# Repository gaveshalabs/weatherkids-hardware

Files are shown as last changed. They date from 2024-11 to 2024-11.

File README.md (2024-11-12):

# WeatherKids Weather Computer

WeatherKids is an engaging climate education program where children learn about climate change hands-on using a small, open-source weather station called the **Weather Computer**. This repository contains source code for both versions, **v1.0** and **v2.0**, of the Weather Computer. It is licensed under the **CERN Open Hardware License - W**, making it free to use, modify, and share in compliance with the license terms.

## Overview

The WeatherKids Weather Computer is designed to help young learners understand key aspects of weather and climate. Through real-time data collection and analysis, children learn about:

- Temperature
- Humidity
- Atmospheric Pressure
- And optional TVOC sensor

These metrics contribute to building awareness around climate science and inspire further exploration in STEM.

## Versions

### Version 1.0
- **Released**: 2022 December
- **Features**: 
    - Basic weather measurements (temperature, humidity,  pressure and optional TVOC sensor)
 
KNOWN issues - Charging mechanism doesn't work properly in fog conditions

### Version 2.0
- **Released**: 2023 December
- **Features**: 
    - Compact design with Li-Polimer battery
    - Sperate Action card to mearsure solar power and provide power to main board.

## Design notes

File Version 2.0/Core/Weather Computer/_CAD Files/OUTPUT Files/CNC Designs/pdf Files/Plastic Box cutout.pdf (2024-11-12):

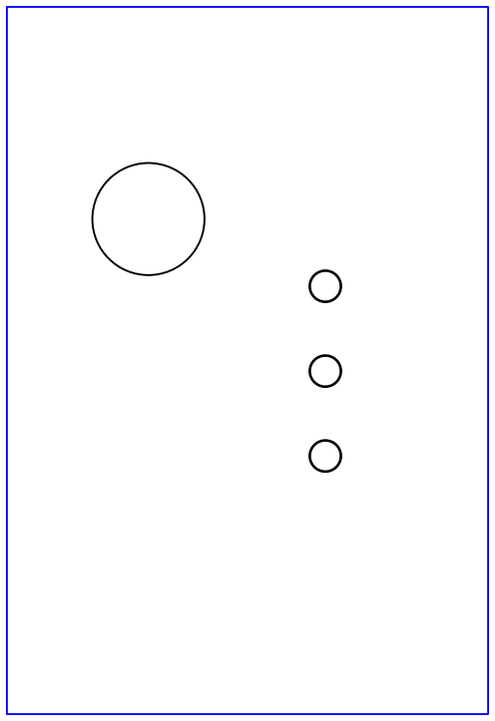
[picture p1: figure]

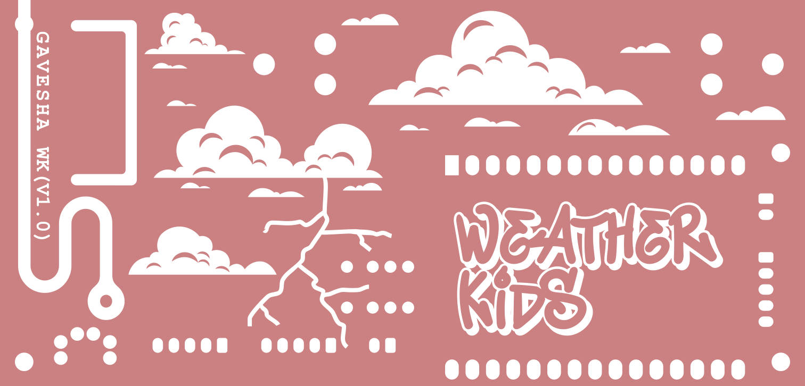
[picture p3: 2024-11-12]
Version 2.0/Core/Weather Computer/PROJECT_LIB/Bottom SilkScreen.png

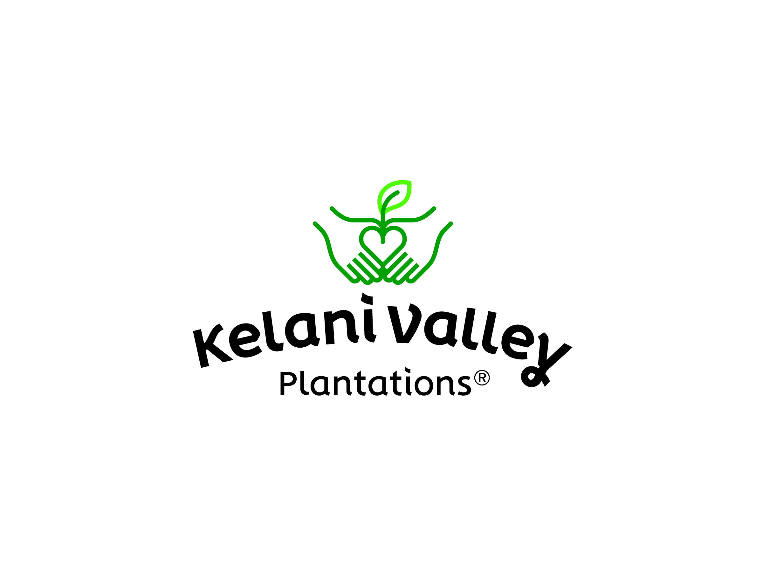
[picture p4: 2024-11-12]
Version 2.0/Core/Weather Computer/_CAD Files/Stickers/Resource Files/KVPL_CMYK.jpg

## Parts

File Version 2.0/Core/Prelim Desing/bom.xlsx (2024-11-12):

Designator | Footprint | Value | JLCPCB Part #
C1, C10, C13 | 402 | 1uF | C52923
C11 | 603 | 22uF | C59461
C12 | 402 | 0.1uF | C141382
C14, C15, C17, C24, C7, C9 | 805 | 10uF | C15850
C16, C18, C19, C2, C20, C21, C4 | 402 | 100nF | C1525
C23 | CP_EIA-3528-12_Kemet-T | 100uF | C16133
C25 | 402 | 4.7uF | C23733
C5 | 402 | 10uF | C15525
C6 | 603 | 47nF | C1622
C8 | 402 | 1nF | C1523
D1, D2, D5 | 805 | LED | C34499
D3 | D_SOD-323 | SS54 | C2128
D4 | D_SMA | SS54 | C22452
J1 | JST_PH_S2B-PH-SM4-TB_1x02-1MP_P2.00mm_Horizontal | Conn_01x02 | C295747
L1, L2 | WPN252010U | 1uH | C279952
R1 | 402 | 3.3k | C310224
R10, R2, R7 | 402 | 330R | C25104
R3,R11, R12, R13, R15, R17, R18, R19, R20, R21, R22, R23, R4, R8, R9 | 402 | 10k | C25744
R14 | 603 | 450k | C1395420
R16 | 402 | 200k | C25764
R24 | 402 | 3.6k | C310258
R5 | 402 | 510k | C11616
R6 | 402 | 68k | C36871
RV1 | 402 | AVRM1005C6R8NT331N | C574031
SW1, SW2, SW3, SW4 | SKRTLB | SW_Push | C127481
U1 | Texas_S-PWQFN-N24_EP2.7x2.7mm_ThermalVias | BQ25601 | C468236
U10, U11, U12, U13, U14 | SOT-23-5 | SN74LV1T34DVBR | C100024
U3 | DRL0006A | TPS61023DRL | C919459
U4 | SOT-223 | TLV1117LV30DCYR | C507264
U5 | AGS10 | AGS10 | C3012632
U6 | AHT20 | AHT20 | C3012622
U7 | SOIC-8_3.9x4.9mm_P1.27mm | PCF8563T | C7440
U8 | Bosch_LGA-8_2x2.5mm_P0.65mm_ClockwisePinNumbering | BMP280 | C83291
U9 | PCA9306DCUR | PCA9306DCUR | C33196
Y1 | Crystal_SMD_3215-2Pin_3.2x1.5mm | 32.768kHz | C32346

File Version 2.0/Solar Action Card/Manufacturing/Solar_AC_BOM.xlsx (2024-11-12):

C14663 | Footprint | Quantity | Value | LCSC Part #
C1, C16, C2, C10, C11, C13, C6 | 603 | 7 | 100nF | C14663
C12 | 603 | 1 | 10uF | C96446
C14 | 603 | 1 | 3.3nF | C1613
C15 | 603 | 1 | 22uF | C59461
C3 | 402 | 1 | 4.7uF | C23733
C4 | 402 | 1 | 10nF | C15195
C5 | 402 | 1 | 1uF | C52923
C8 | CP_EIA-3528-12_Kemet-T | 1 | 100uF | C16133
C9 | 805 | 1 | 10uF | C15850
J4 | USB_C_Receptacle_HRO_TYPE-C-31-M-12 | 1 | USB_C_Receptacle_USB2.0 | C165948
L1 | L_Sunlord_MWSA0518_5.4x5.2mm | 1 | 2.2uH | C408345
Q1, Q2 | SOT-23 | 2 | 2N7002E | C8545
R1, R15, R16, R2, R3, R5, R7, R8, R12 | 402 | 9 | 10k | C25744
R10 | 603 | 1 | 750k | C441908
R11 | 603 | 1 | 270k | C2889163
R13 | 1206 | 1 | 50m | C912768
R14 | R_Axial_DIN0516_L15.5mm_D5.0mm_P20.32mm_Horizontal | 1 | 130R | C119572 | C5166557
R6 | 402 | 1 | 200k | C25764
R9 | 402 | 1 | 100k | C25741
U1 | LQFP-48_7x7mm_P0.5mm | 1 | STM32F103C8Tx | C8734
U10 | SOT-23-5 | 1 | INA180A1 | C122228
U2 | PCA9306DCUR | 1 | PCA9306DCUR | C33196
U7 | SOT-223 | 1 | AZ1117-3.3 | C6186
U8 | VQFN-16-1EP_3x3mm_P0.5mm_EP1.68x1.68mm_ThermalVias | 1 | TPS62133 | C73973
U9 | MSOP-8-1EP_3x3mm_P0.65mm_EP1.95x2.15mm | 1 | TPS1H000AQDGNRQ1 | C2653764

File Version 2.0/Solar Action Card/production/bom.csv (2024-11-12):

Designator | Footprint | Quantity | Value | LCSC Part #
C1, C16, C2 | 0603 | 3 | 100nF
C10 | 0603 | 1 | 0.1uF
C11 | 0805 | 1 | 0.1uF
C12 | 0402 | 1 | 10uF
C13, C6 | 0402 | 2 | 100nF
C14 | 0402 | 1 | 3.3nF
C15 | 0603 | 1 | 22uF
C3 | 0402 | 1 | 4.7uF
C4 | 0402 | 1 | 10nF
C5 | 0402 | 1 | 1uF
C8 | CP_EIA-3528-12_Kemet-T | 1 | 100uF
C9 | 0805 | 1 | 10uF
J3 | 3126-XXXX | 1 | 3126-10200D
J4 | USB_C_Receptacle_HRO_TYPE-C-31-M-12 | 1 | USB_C_Receptacle_USB2.0
L1 | L_Sunlord_MWSA0518_5.4x5.2mm | 1 | 2.2uH | C408345
Q1, Q2 | SOT-23 | 2 | 2N7002E
R1, R15, R16, R2, R3, R5, R7, R8 | 0402 | 8 | 10k
R10 | 0603 | 1 | 750k
R11 | 0603 | 1 | 270k
R12 | 0603 | 1 | 10k
R13 | 1206 | 1 | 50m
R14 | R_Axial_DIN0516_L15.5mm_D5.0mm_P20.32mm_Horizontal | 1 | 130R
R4 | 0402 | 1 | 450k
R6 | 0402 | 1 | 200k
R9 | 0402 | 1 | 100k
U1 | LQFP-48_7x7mm_P0.5mm | 1 | STM32F103C8Tx
U10 | SOT-23-5 | 1 | INA180A1
U2 | PCA9306DCUR | 1 | PCA9306DCUR
U7 | SOT-223 | 1 | AZ1117-3.3
U8 | VQFN-16-1EP_3x3mm_P0.5mm_EP1.68x1.68mm_ThermalVias | 1 | TPS62133 | C2653764
U9 | MSOP-8-1EP_3x3mm_P0.65mm_EP1.95x2.15mm | 1 | TPS1H000AQDGNRQ1

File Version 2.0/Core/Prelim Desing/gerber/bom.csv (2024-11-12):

Designator | Footprint | Quantity | Value | LCSC Part #
C1, C10, C13 | 0402 | 3 | 1uF
C11 | 0603 | 1 | 22uF
C12 | 0402 | 1 | 0.1uF
C14, C15, C17, C24, C7, C9 | 0805 | 6 | 10uF
C16, C18, C19, C2, C20, C21, C4 | 0402 | 7 | 100nF
C23 | CP_EIA-3528-12_Kemet-T | 1 | 100uF
C25 | 0402 | 1 | 4.7uF
C5 | 0402 | 1 | 10uF
C6 | 0603 | 1 | 47nF
C8 | 0402 | 1 | 1nF
D1, D2, D5 | 0805 | 3 | LED
D3 | D_SOD-323 | 1 | SS54
D4 | D_SMA | 1 | SS54
H1, H2 | MountingHole_2.2mm_M2 | 2 | MountingHole
J1 | JST_PH_S2B-PH-SM4-TB_1x02-1MP_P2.00mm_Horizontal | 1 | Conn_01x02
J3 | 3126-XXXX | 1 | 3126-10200D
L1, L2 | WPN252010U | 2 | 1uH
R1 | 0402 | 1 | 3.3k
R10, R2, R7 | 0402 | 3 | 330R
R11, R12, R13, R15, R17, R18, R19, R20, R21, R22, R23, R3, R4, R8, R9 | 0402 | 15 | 10k
R14 | 0603 | 1 | 450k
R16 | 0402 | 1 | 200k
R24 | 0402 | 1 | 3.6k
R5 | 0402 | 1 | 510k
R6 | 0402 | 1 | 68k
RV1 | 0402 | 1 | AVRM1005C6R8NT331N
SW1, SW2, SW3, SW4 | SKRTLB | 4 | SW_Push
U1 | Texas_S-PWQFN-N24_EP2.7x2.7mm_ThermalVias | 1 | BQ25601
U10, U11, U12, U13, U14 | SOT-23-5 | 5 | SN74LV1T34DVBR
U2 | ESP32-WROOM-32 | 1 | ESP32-WROOM-32D
U3 | DRL0006A | 1 | TPS61023DRL
U4 | SOT-223 | 1 | TLV1117LV30DCYR
U5 | AGS10 | 1 | AGS10
U6 | AHT20 | 1 | AHT20
U7 | SOIC-8_3.9x4.9mm_P1.27mm | 1 | PCF8563T
U8 | Bosch_LGA-8_2x2.5mm_P0.65mm_ClockwisePinNumbering | 1 | BMP280
U9 | PCA9306DCUR | 1 | PCA9306DCUR
Y1 | Crystal_SMD_3215-2Pin_3.2x1.5mm | 1 | 32.768kHz

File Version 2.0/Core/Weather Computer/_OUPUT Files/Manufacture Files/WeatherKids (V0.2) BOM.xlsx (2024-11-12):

Index | Availability | Checked | Layer | Special Notes |  | Value | Footprint |  | JLC Basic Part Match | JLCPCBA part | LCSC Part Number | Manufacturer Part Number | Manufacture | Unit Price | Total
1 | YES |  |  |  | C2, C3, C4, C6, C7, C9 | 100nF | Capacitor_SMD:C_0402_1005Metric | 6 | Y | C1525 | C60474 | CC0402KRX7R7BB104 |  | 0.0008 | 0.0048
2 | YES |  |  |  | C10 | 12pF | Capacitor_SMD:C_0402_1005Metric | 1 | Y | C1547 | C106201 | CC0402JRNPO9BN120 |  | 0.001 | 0.001
3 | YES |  |  |  | C5, C8, C11, C12, C13, C15, C16 | 10uF | Capacitor_SMD:C_0805_2012Metric | 7 | Y | C15850 | C89827 | CC0805KKX5R7BB106 |  | 0.0275 | 0.1925
4 | YES |  |  |  | D6 | SS34 | Diode_SMD:D_SMA | 1 | Y | C8678 | C8678 | SS34 |  | 0.0278 | 0.0278
5 | YES |  |  |  | D4 | BAV70 | Package_TO_SOT_SMD:SOT-23 | 1 | Y | C68978 | C68978 | BAV70 |  | 0.0185 | 0.0185
6 | YES |  |  |  | D1, D2, D5 | LED | LED_SMD:LED_0805_2012Metric | 3 | Y | C34499 | C34499 | C34499 | Hubei KENTO Elec | 0.0157 | 0.0471
7 | YES |  |  |  | J1, J2, J3 | Conn_01x05 | Connector_JST:JST_PH_S5B-PH-K_1x05_P2.00mm_Horizontal | 3 | N | C10402 | C442192 | HX20007-5WAD |  | 0.0305 | 0.0915
8 | YES |  |  |  | J4, J5 | Conn_01x02 | Connector_JST:JST_PH_S2B-PH-K_1x02_P2.00mm_Horizontal | 2 | N | C16965 | C16965 | PH-2AW |  | 0.0056 | 0.0112
 | YES |  |  |  | J6, J7 | CONN1X15 | 2.54 Female connector | 2 | N | C124408 | C124408 | B-2200S15P-A120 |  | 0.1518 | 0.3036
9 | YES |  |  |  | J9, J10 | MY-18650-01 | Myoung:MY-18650-01 | 2 | N | C2979183 | C2979183 | MY-18650-01 |  | 0.3052 | 0.6104
10 | YES |  |  |  | L1 | 1uH | Inductor_SMD:L_Taiyo-Yuden_NR-20xx | 1 | N | C279952 | C279952 | WPN252010U1R0MT |  | 0.0572 | 0.0572
11 | YES |  |  |  | L2 | 2.2uH | Sunlord Inductors:WPN252010U | 1 | N | C279871 | C279871 | WPN252010U2R2MT |  | 0.0517 | 0.0517
12 | YES |  |  |  | Q1 | AO3400A | Package_TO_SOT_SMD:SOT-23 | 1 | Y | C20917 | C20917 | AO3400A |  | 0.079 | 0.079
13 | YES |  |  |  | R2 | 1R | Resistor_SMD:R_1206_3216Metric | 1 | Y | C17928 | C17928 | 1206W4F100KT5E |  | 0.0044 | 0.0044
14 | YES |  |  |  | R4, R14, R25 | 330R | Resistor_SMD:R_0402_1005Metric | 1 | Y | C25104 | C25104 | 0402WGF3300TCE |  | 0.0005 | 0.0005
15 | YES |  |  |  | R5, R23, R24 | 4.7k | Resistor_SMD:R_0402_1005Metric | 3 | Y | C25900 | C25900 | 0402WGF4701TCE |  | 0.0006 | 0.0018
16 | YES |  |  |  | R3, R6, R7, R10 | 0R | Resistor_SMD:R_0402_1005Metric | 4 | Y | C17168 | C17168 | 0402WGF0000TCE |  | 0.0005 | 0.002
17 | YES |  |  |  | R1, R8, R9, R11, R15, R22 | 10k | Resistor_SMD:R_0402_1005Metric | 6 | Y | C25744 | C60490 | RC0402FR-0710KL |  | 0.0005 | 0.003
18 | YES |  |  |  | R16 | 1k | Resistor_SMD:R_0402_1005Metric | 1 | Y | C11702 | C11702 | 0402WGF1001TCE |  | 0.0005 | 0.0005
19 | YES |  |  |  | R17 | 2k | Resistor_SMD:R_0603_1608Metric | 1 | y | C4109 | C4109 | 0402WGF2001TCE |  | 0.0005 | 0.0005
20 | YES |  |  |  | R12, R13, R18 | 100k | Resistor_SMD:R_0402_1005Metric | 3 | y | C25741 | C25741 | 0402WGF1003TCE |  | 0.0005 | 0.0015
21 | YES |  |  |  | R19 | 510k | Resistor_SMD:R_0402_1005Metric | 1 | y | C11616 | C11616 | 0402WGF5103TCE |  | 0.0006 | 0.0006
22 | YES |  |  |  | R20 | 22k | Resistor_SMD:R_0402_1005Metric | 1 | Y | C25768 | C25768 | 0402WGF2202TCE |  | 0.0005 | 0.0005
23 | YES |  |  |  | R26 | 100R | Resistor_SMD:R_1206_3216Metric | 1 | Y | C17901 | C17901 | 1206W4F1000T5E |  | 0.0029 | 0.0029
24 | YES |  |  |  | R21 | 68k | Resistor_SMD:R_0402_1005Metric | 1 | y | C36871 | C36871 | 0402WGF6802TCE |  | 0.0006 | 0.0006
25 | YES |  |  |  | SW1 | HFD4_5S | Xiamen_Hiongfa:HDF4 | 1 | N | C23510 | C23510 | HFD4/5 |  | 1.0077 | 1.0077
26 | YES |  |  |  | SW2 | SW_SPST | XKB:XKB5858-X-E | 1 | N | C780038 | C780038 | XKB5858-Z-E |  | 0.2148 | 0.2148
27 | YES |  |  |  | U2 | INA180A2 | Package_TO_SOT_SMD:SOT-23-5 | 1 | N | C192764 | C192764 | INA180A2IDBVR |  | 0.2574 | 0.2574
28 | YES |  |  |  | U3 | BMP280 | Package_LGA:Bosch_LGA-8_2x2.5mm_P0.65mm_ClockwisePinNumbering | 1 | N | C83291 | C83291 | BMP280 |  | 1.5547 | 1.5547
29 | YES |  |  |  | U4 | AGS10 | ASAIR Sensors:AGS10 | 1 | N | C3012632 | C3012632 | AGS10 |  | 1.4497 | 1.4497
30 | YES |  |  |  | U5 | AHT20 | ASAIR Sensors:AHT20 | 1 | N | C3012622 | C3012622 | AHT20-F |  | 0.7037 | 0.7037
31 | YES |  |  |  | U6 | TP4057 | Package_TO_SOT_SMD:SOT-23-6 | 1 | N | C12044 | C12044 | TP4057-42-SOT26-R |  | 0.1281 | 0.1281
32 | YES |  |  |  | U7 | RT8059GJ5 | Package_TO_SOT_SMD:TSOT-23-5 | 1 | N | C20542 | C20542 | RT5796CHGJ5 |  | 0.2 | 0.2
33 | YES |  |  |  | U1 | TPS61023DRL | Texas_Instruments:DRL0006A | 1 | N | C919459 | C919459 | TPS61023DRLR |  | 0.277 | 0.277
34 | YES |  |  |  | U9 | PCF8563T | Package_SO:SOIC-8_3.9x4.9mm_P1.27mm | 1 | Y | C7440 | C7440 | PCF8563T/5,518 |  | 0.5877 | 0.5877
35 | YES |  |  |  | Y1 | 32.768kHz | Crystal:Crystal_SMD_3215-2Pin_3.2x1.5mm | 1 | Y | C32346 | C32346 | Q13FC1350000400 |  | 0.1978 | 0.1978
36 | YES |  | NA | ESP32 DevKit | MOD1 | ESP32_DEVKIT_V1 | Espressif_Systems:ESP32_DEVKIT_V1.0 | 1 | N |  |  | ESP32_DEVKIT_V1 |  | 3.947368421 | 3.947368421
37 | YES |  | NA | 1800 mAh Batter | Battery | Batttery | Li-ion battery | 1 | N |  |  | Batttery |  | 1.5 | 1.5
38 | YES |  | NA | 2 Layer PCB Cost | PCB |  |  | 1 | N |  |  |  |  | 0.51 | 0.51
39 | YES |  | NA | Soldering (single side) | Assembly Fee |  |  | 1 | N |  |  |  |  | 2.3 | 2.3
40 | YES |  | NA | 3D printed casing | Casing |  |  | 1 | N |  |  |  |  | 3 | 3
41 | YES |  | NA | Shipping cost from china to Sri Lanka | Direct Shipping cost |  |  | 1 | N |  |  |  |  | 3.5 | 3.5
42 | YES |  |  |  | H1-H4 | Screws |  | 4 | N
 |  |  |  |  |  |  |  |  |  |  |  |  | Total without Tax |  | 22.85106842
 |  |  |  |  |  |  |  |  |  |  |  |  | Total with Tax |  | 24.67915389
 |  |  |  |  |  |  |  |  |  |  |  |  | Total with 10% error Margine |  | 27.14706928
 |  |  |  |  |  |  |  |  |  |  |  |  | Final Cost (LKR) |  | 10315.88633

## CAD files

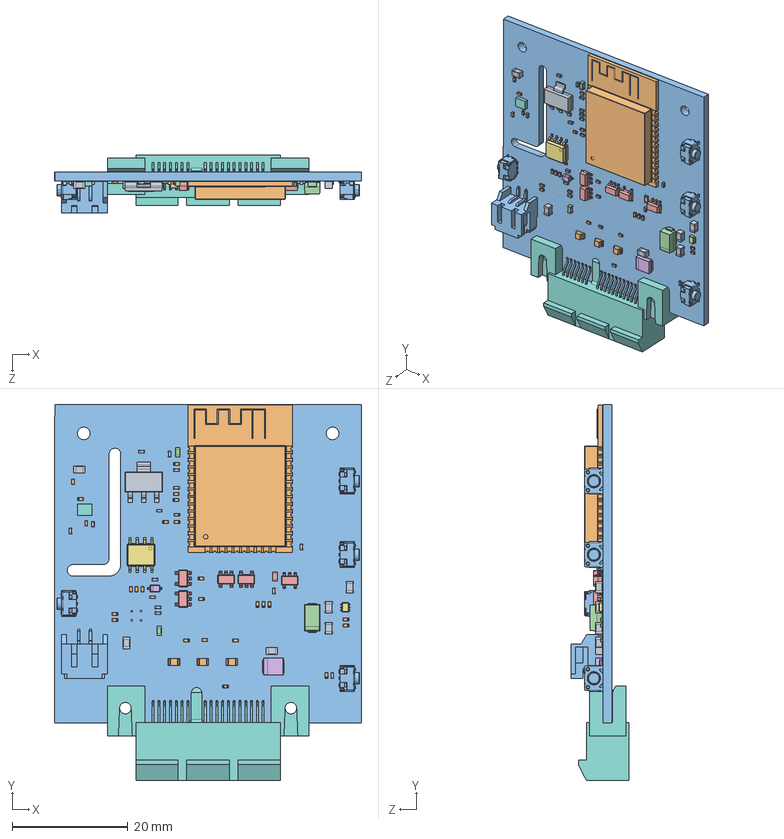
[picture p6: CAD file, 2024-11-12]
Version 2.0/Core/Weather Computer/ENC/Weather Computer.SLDASM
53.0 x 65.0 x 10.1 mm
SOLID.step x 14
SOLID-0.step x 26
COMPOUND.step
SOLID-1.step x 2
SOLID-2.step x 5
SOLID-3.step
COMPOUND-4.step
SOLID-5.step
SOLID-6.step x 6
SOLID-7.step x 3
SOLID-8.step x 4
SOLID-9.step
SOLID-10.step
SOLID-11.step
SOLID-12.step
SOLID-13.step
SOLID-14.step
SOLID-15.step
WeatherKids_V3 PCB.step

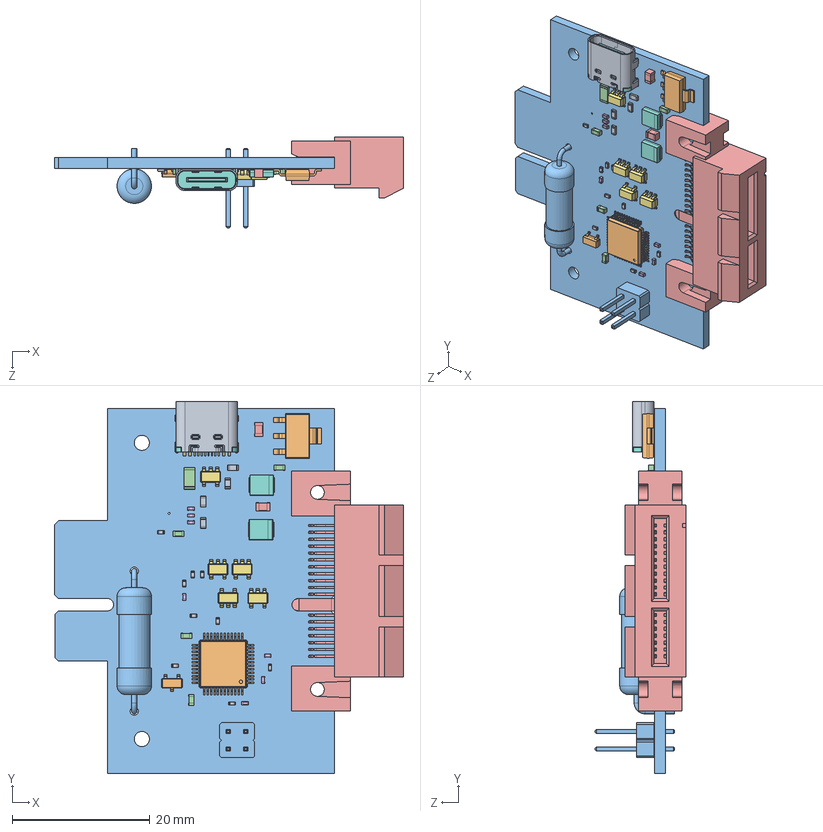
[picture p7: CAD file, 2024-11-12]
Version 2.0/Solar Action Card/ENC/Solar_AC.SLDASM
50.7 x 54.0 x 13.1 mm
SOLID.step x 9
SOLID-0.step
SOLID-1.step
SOLID-2.step x 4
SOLID-3.step x 2
SOLID-4.step x 7
SOLID-5.step x 5
SOLID-6.step x 2
SOLID-7.step x 4
SOLID-8.step
SOLID-9.step
SOLID-10.step
SOLID-11.step
SOLID-12.step
SOLID-13.step
SOLID-14.step
SOLID-15.step
SOLID-16.step
Solar_Charger PCB.step

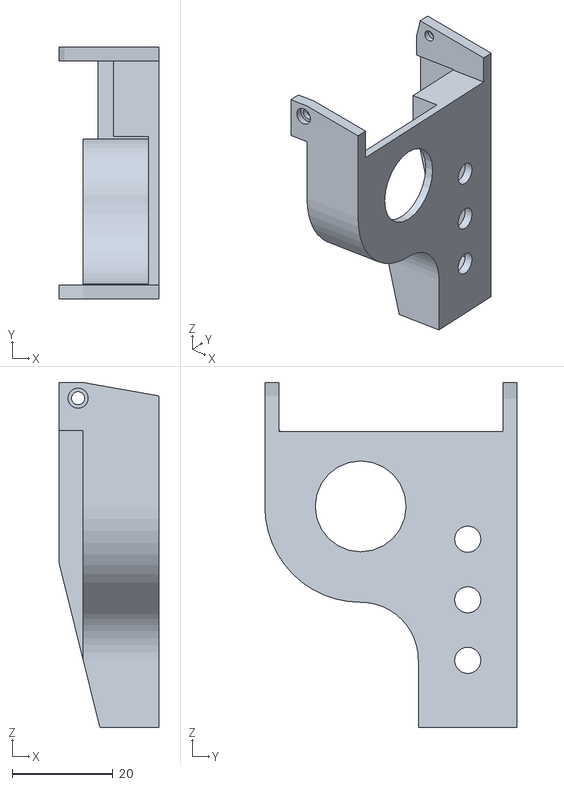
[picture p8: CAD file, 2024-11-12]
Version 2.0/Core/Weather Computer/_CAD Files/3D designs/OUTPUT/Input Panel.stl
19.7 x 50.0 x 68.3

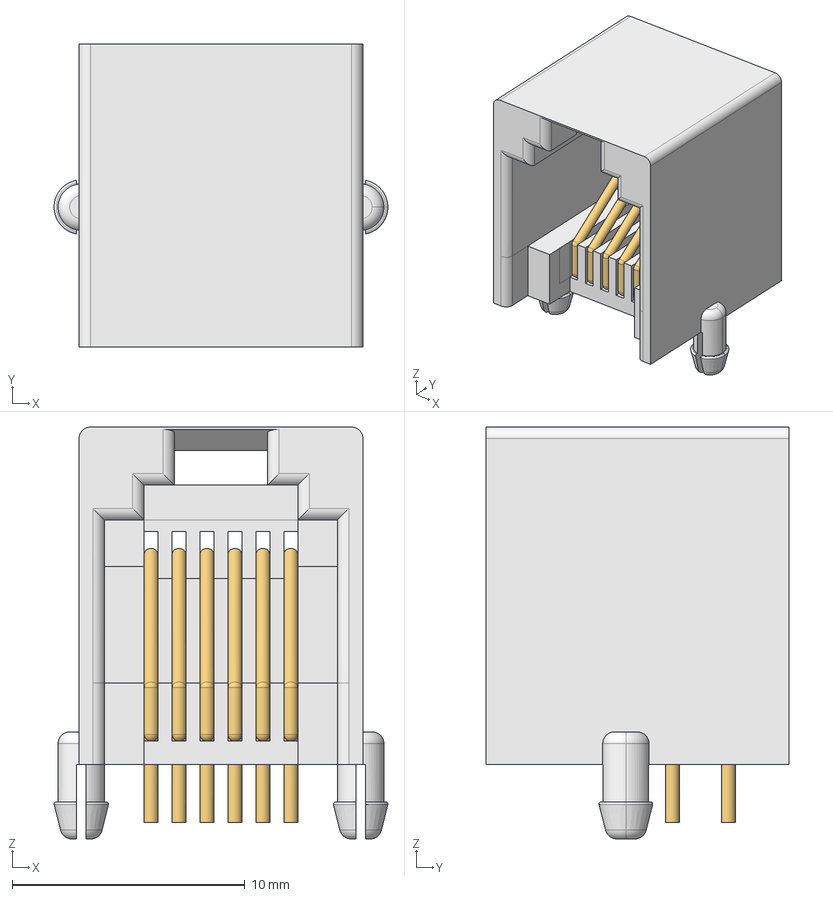
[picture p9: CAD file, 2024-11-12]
Version 2.0/Core/Weather Computer/_CAD Files/Parts/RJ12.step
14.3 x 13.0 x 17.7 mm

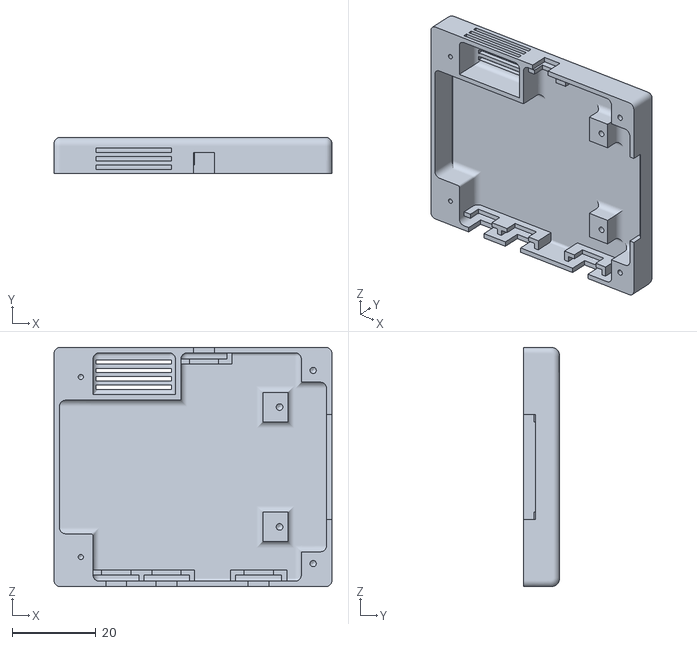
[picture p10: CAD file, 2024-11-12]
Version 2.0/Core/Weather Computer/ENC/Production/WC_Top.STL
66.4 x 8.65 x 57.1

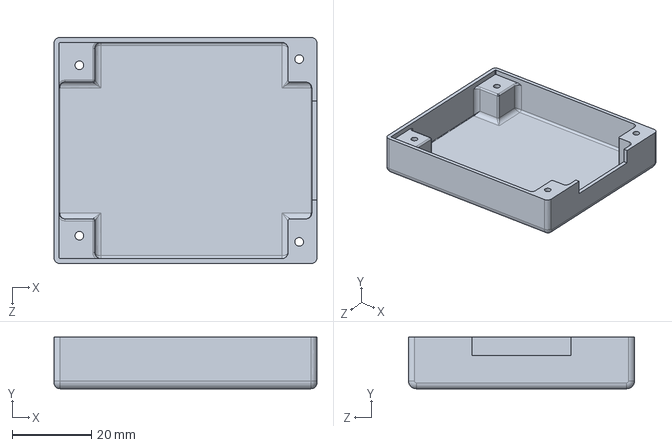
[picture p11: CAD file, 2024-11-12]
Version 2.0/Core/Weather Computer/ENC/WC_Bottom.SLDPRT
66.4 x 13.0 x 57.1 mm

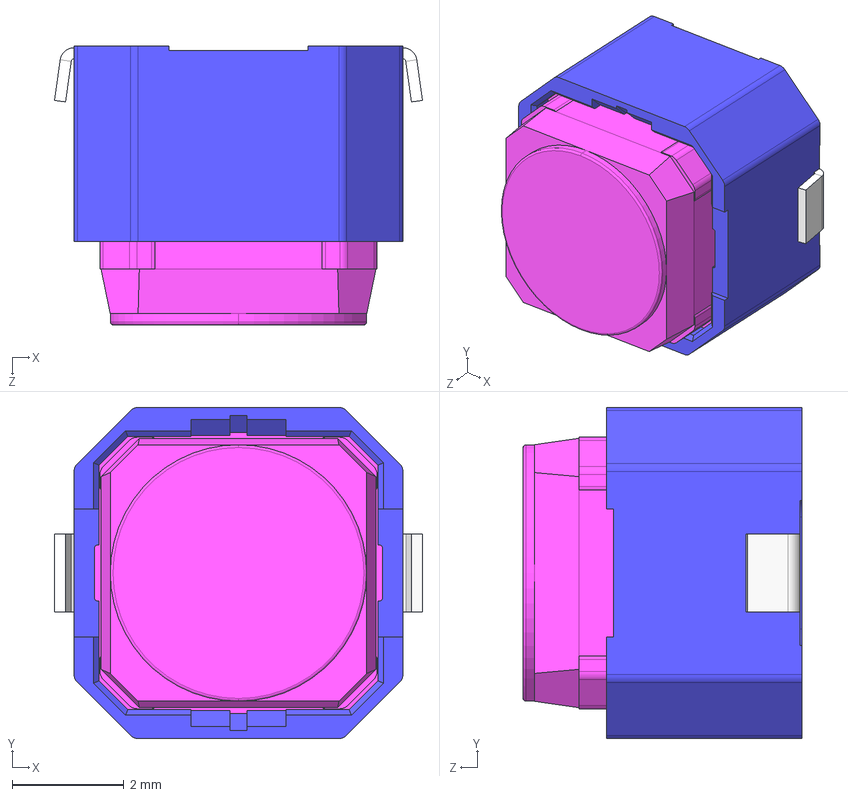
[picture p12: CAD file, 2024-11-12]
Version 2.0/Core/Weather Computer/Notes/foot prints/product_3dcad_skpmame010_en_2a11992c5b/SKPMAME010/SKPMAM.STEP
6.60 x 5.94 x 5.00 mm

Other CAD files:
Version 2.0/Solar Action Card/ENC/C_0402_1005Metric.step.SLDASM
Version 2.0/Solar Action Card/ENC/R_Axial_DIN0516_L15.5mm_D5.0mm_P20.32mm_Horizontal.step.SLDASM
Version 2.0/Solar Action Card/ENC/R_0402_1005Metric.step.SLDASM
Version 2.0/Solar Action Card/ENC/C_0805_2012Metric.step.SLDASM
Version 2.0/Solar Action Card/ENC/R_0603_1608Metric.step.SLDASM
Version 2.0/Solar Action Card/ENC/C_0603_1608Metric.step.SLDASM
Version 2.0/Solar Action Card/ENC/SOT-23-5.step.SLDASM
Version 2.0/Solar Action Card/ENC/PinHeader_2x02_P2.54mm_Vertical.step.SLDASM
Version 2.0/Solar Action Card/ENC/LQFP-48_7x7mm_P0.5mm.step.SLDASM
Version 2.0/Solar Action Card/ENC/SOT-23.step.SLDASM
Version 2.0/Solar Action Card/ENC/CP_EIA-3528-12_Kemet-T.step.SLDASM
Version 1.0/WeatherKids_Compact(V1.0)/_CAD Files/3D designs/OUTPUT/Bucket Bracket.stl
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

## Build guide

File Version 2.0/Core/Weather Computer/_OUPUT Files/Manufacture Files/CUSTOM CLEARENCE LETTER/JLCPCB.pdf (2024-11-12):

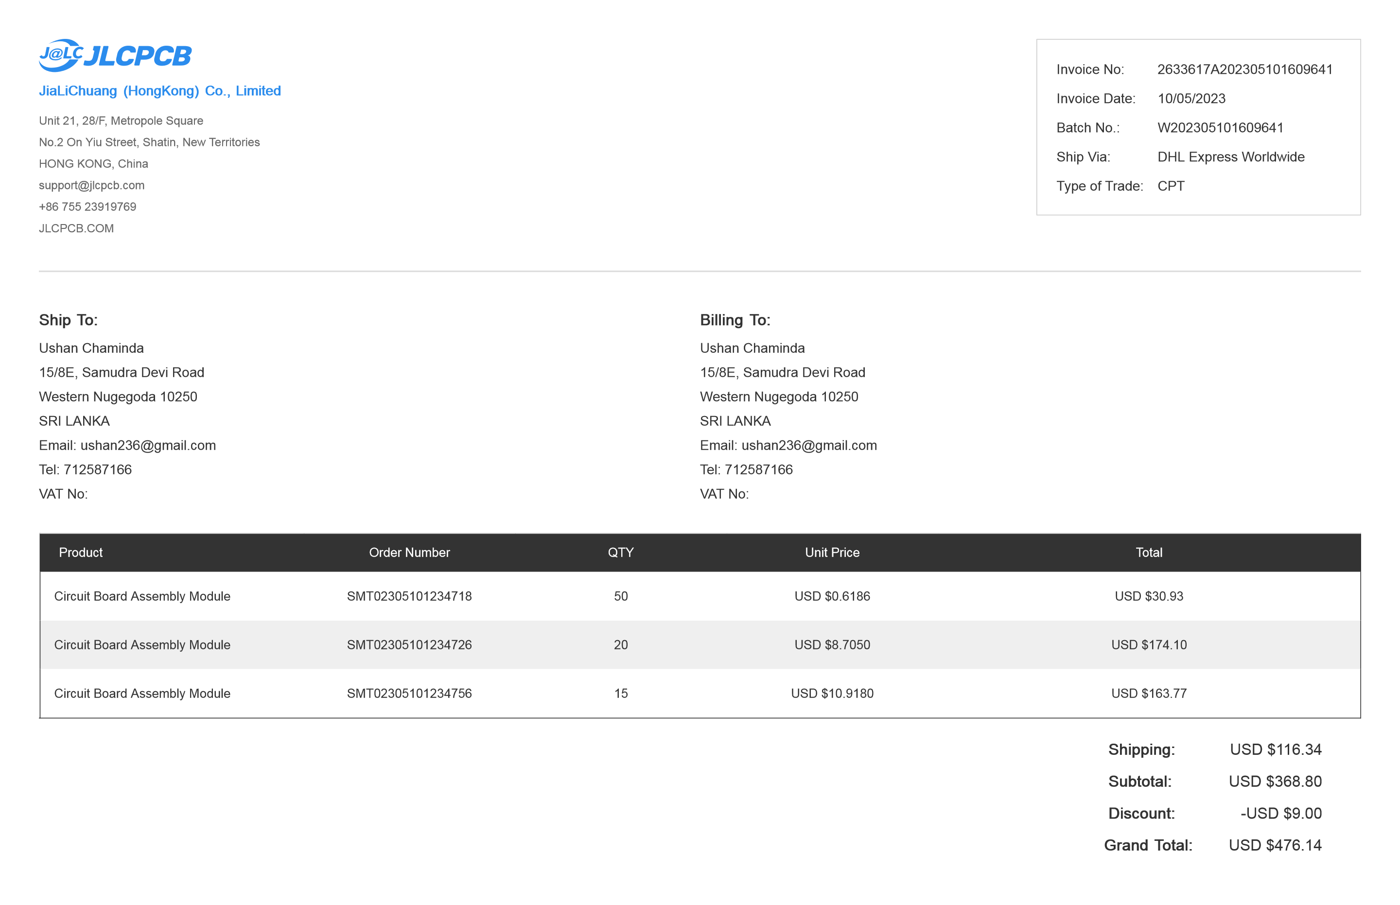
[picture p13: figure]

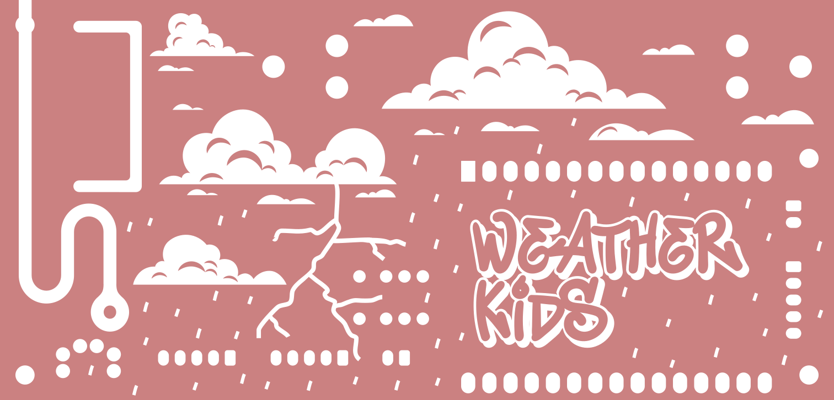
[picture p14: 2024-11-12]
Version 2.0/Core/Weather Computer/_CAD Files/Botom Solder Mask.png

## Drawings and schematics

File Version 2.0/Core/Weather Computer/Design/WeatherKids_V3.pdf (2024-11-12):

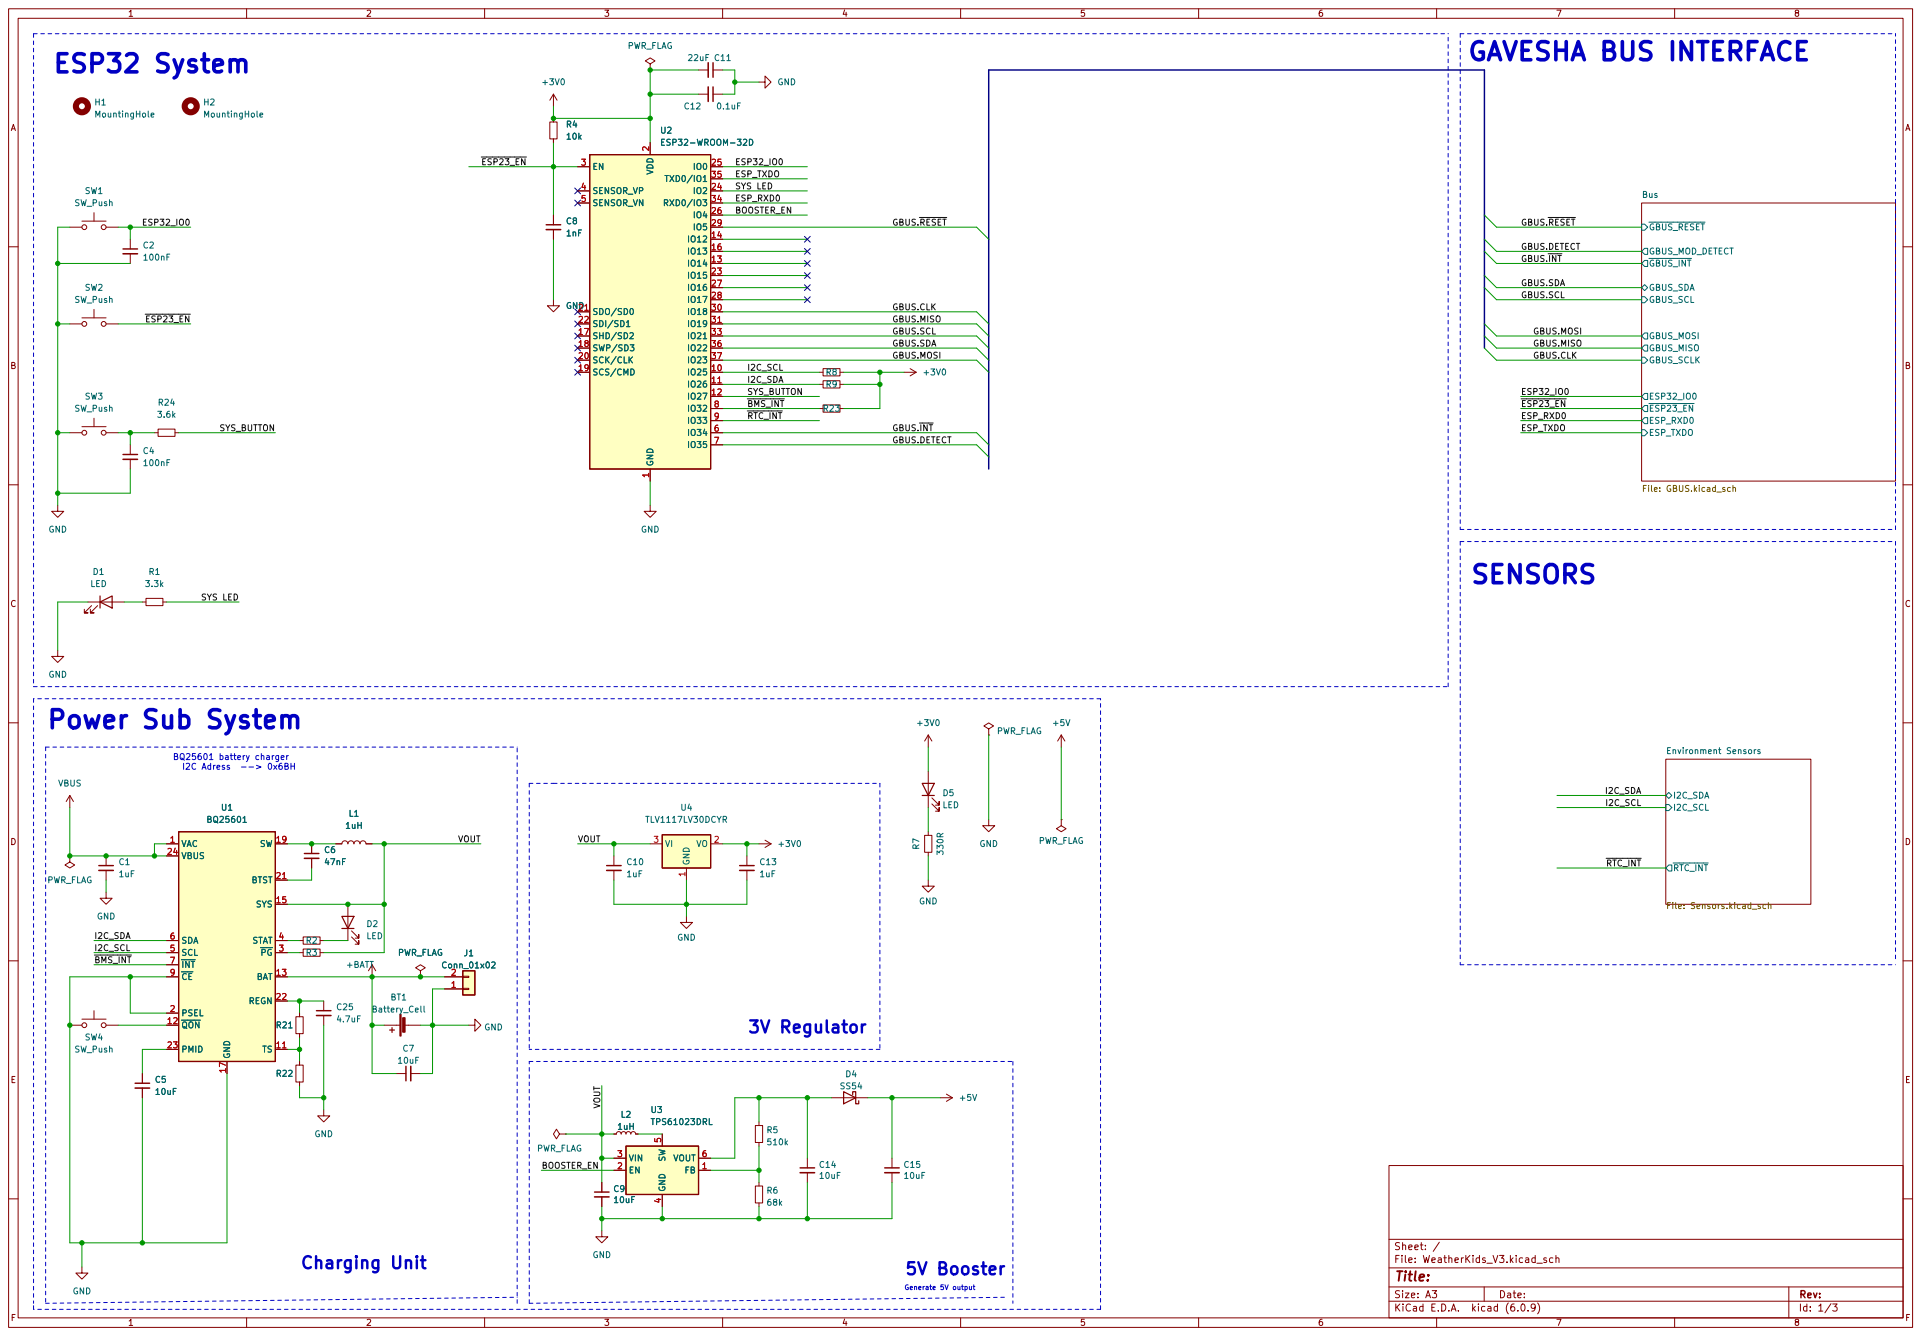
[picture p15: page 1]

2 SCK/CLK 20 SDO/SD0 21 SDI/SD1 22

GBUS.MOSI GBUS.CLK GBUS.~{RESET} ESP_TXDO
~{GBUS_INT} GBUS_MOSI ESP32_IO0 ~{ESP23_EN} ESP_RXD0 ESP_TXDO

GBUS.SCL GBUS.MISO

~{RTC_INT} Environment Sensors File: Sensors.kicad_sch

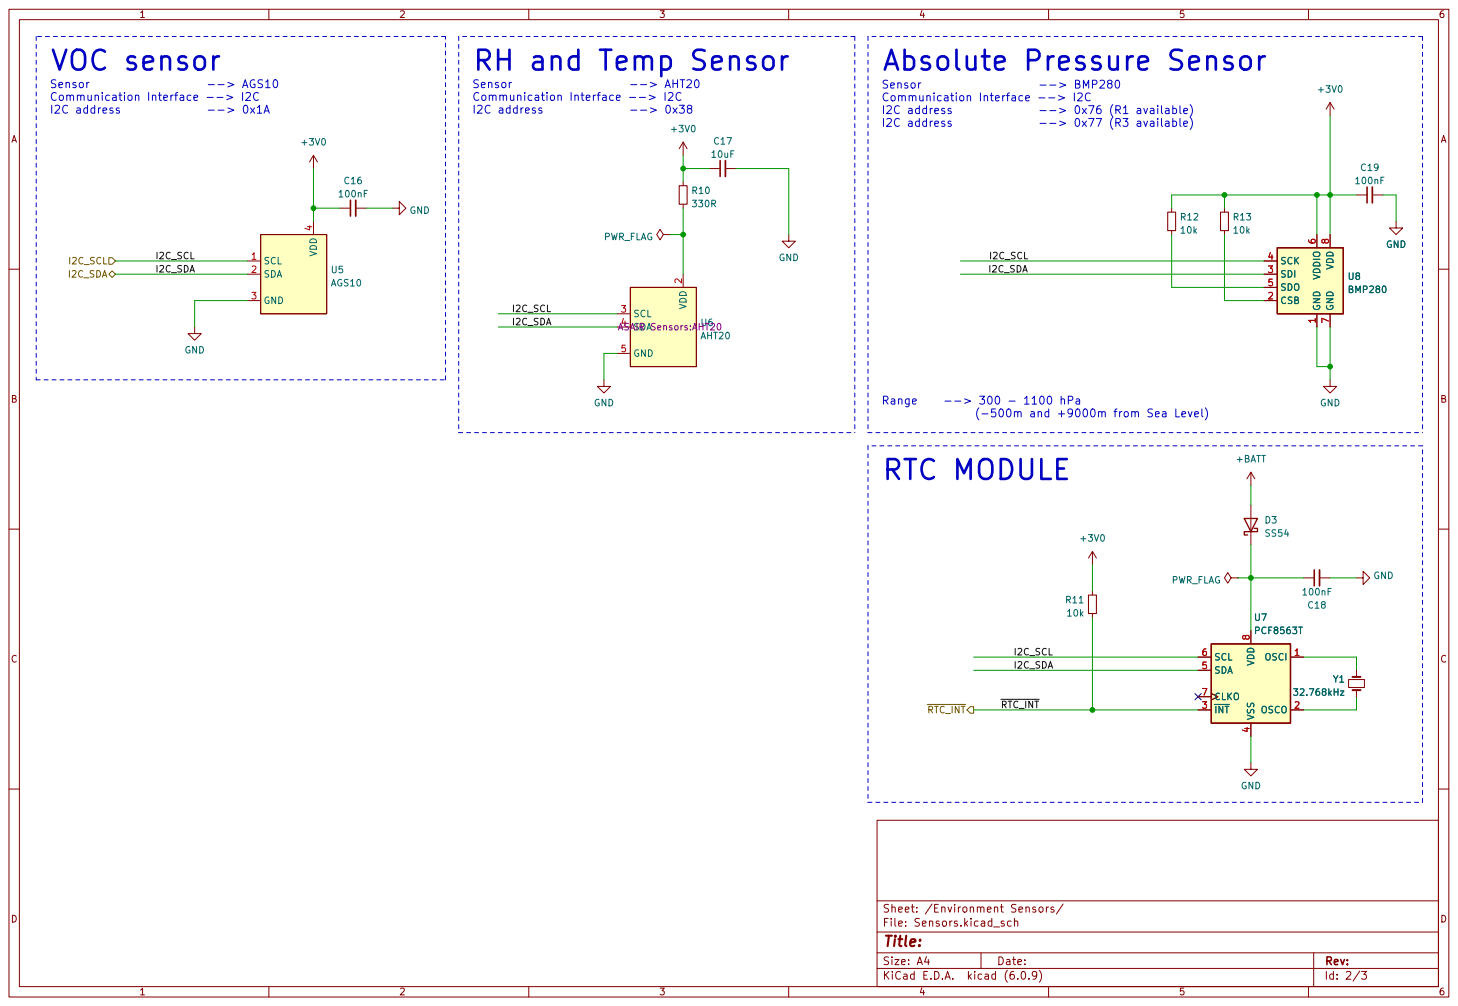
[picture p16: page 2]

2 SCL 3 SDA 4 GND 5 U6 AHT20 ASAIR Sensors:AHT20 C19

1 CSB 2 SDI 3 SCK 4 SDO 5 VDDIO

Range --> 300 - 1100 hPa
(-500m and +9000m from Sea Level)
RTC MODULE

4 SDA 5 SCL 6 CLKO 7 VDD

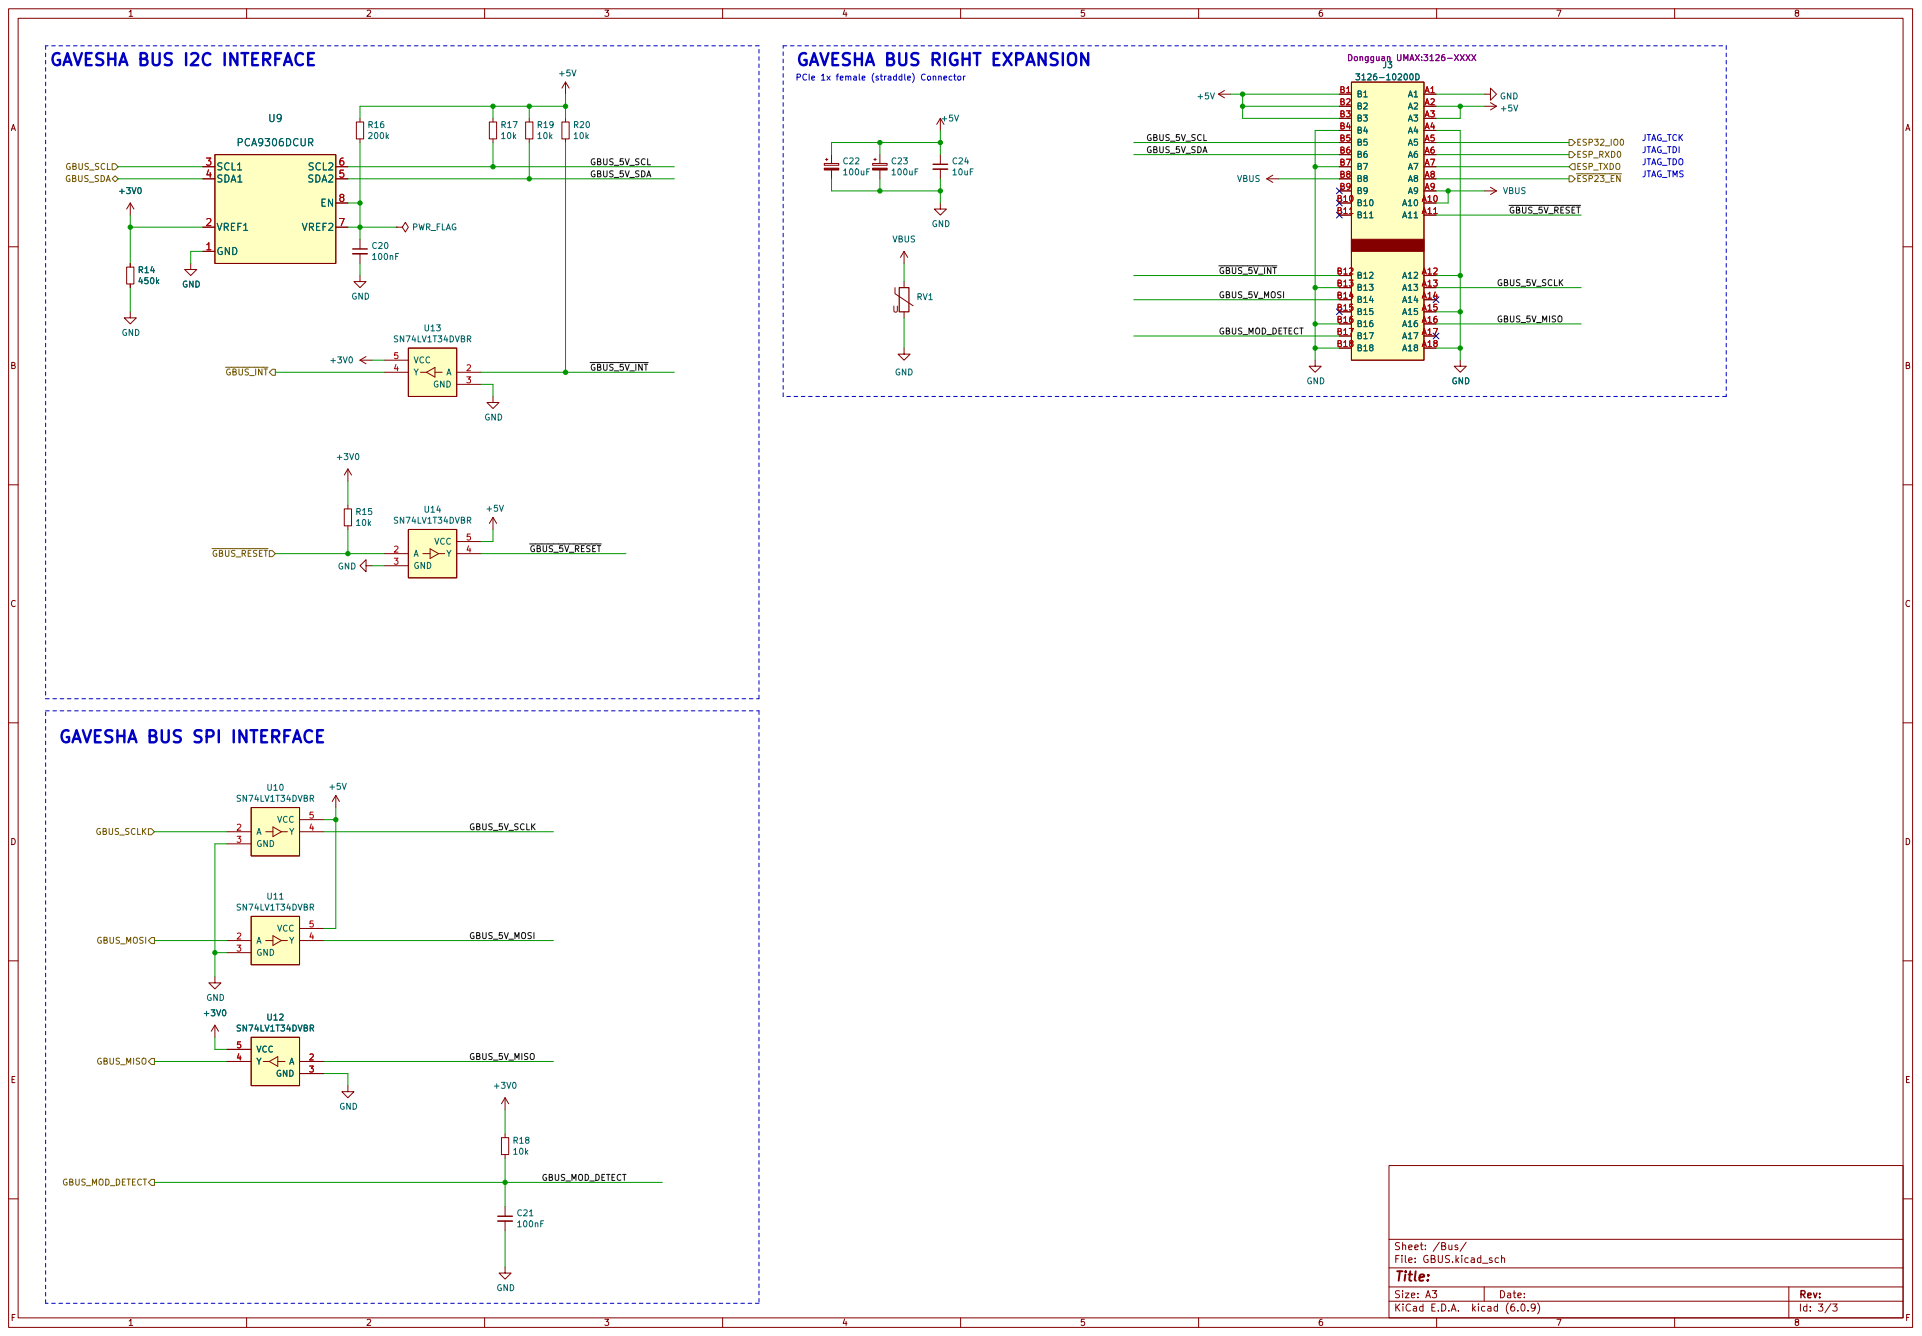
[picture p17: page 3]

JTAG_TDO GAVESHA BUS RIGHT EXPANSION

GAVESHA BUS SPI INTERFACE

File: GBUS.kicad_sch Sheet: /Bus/

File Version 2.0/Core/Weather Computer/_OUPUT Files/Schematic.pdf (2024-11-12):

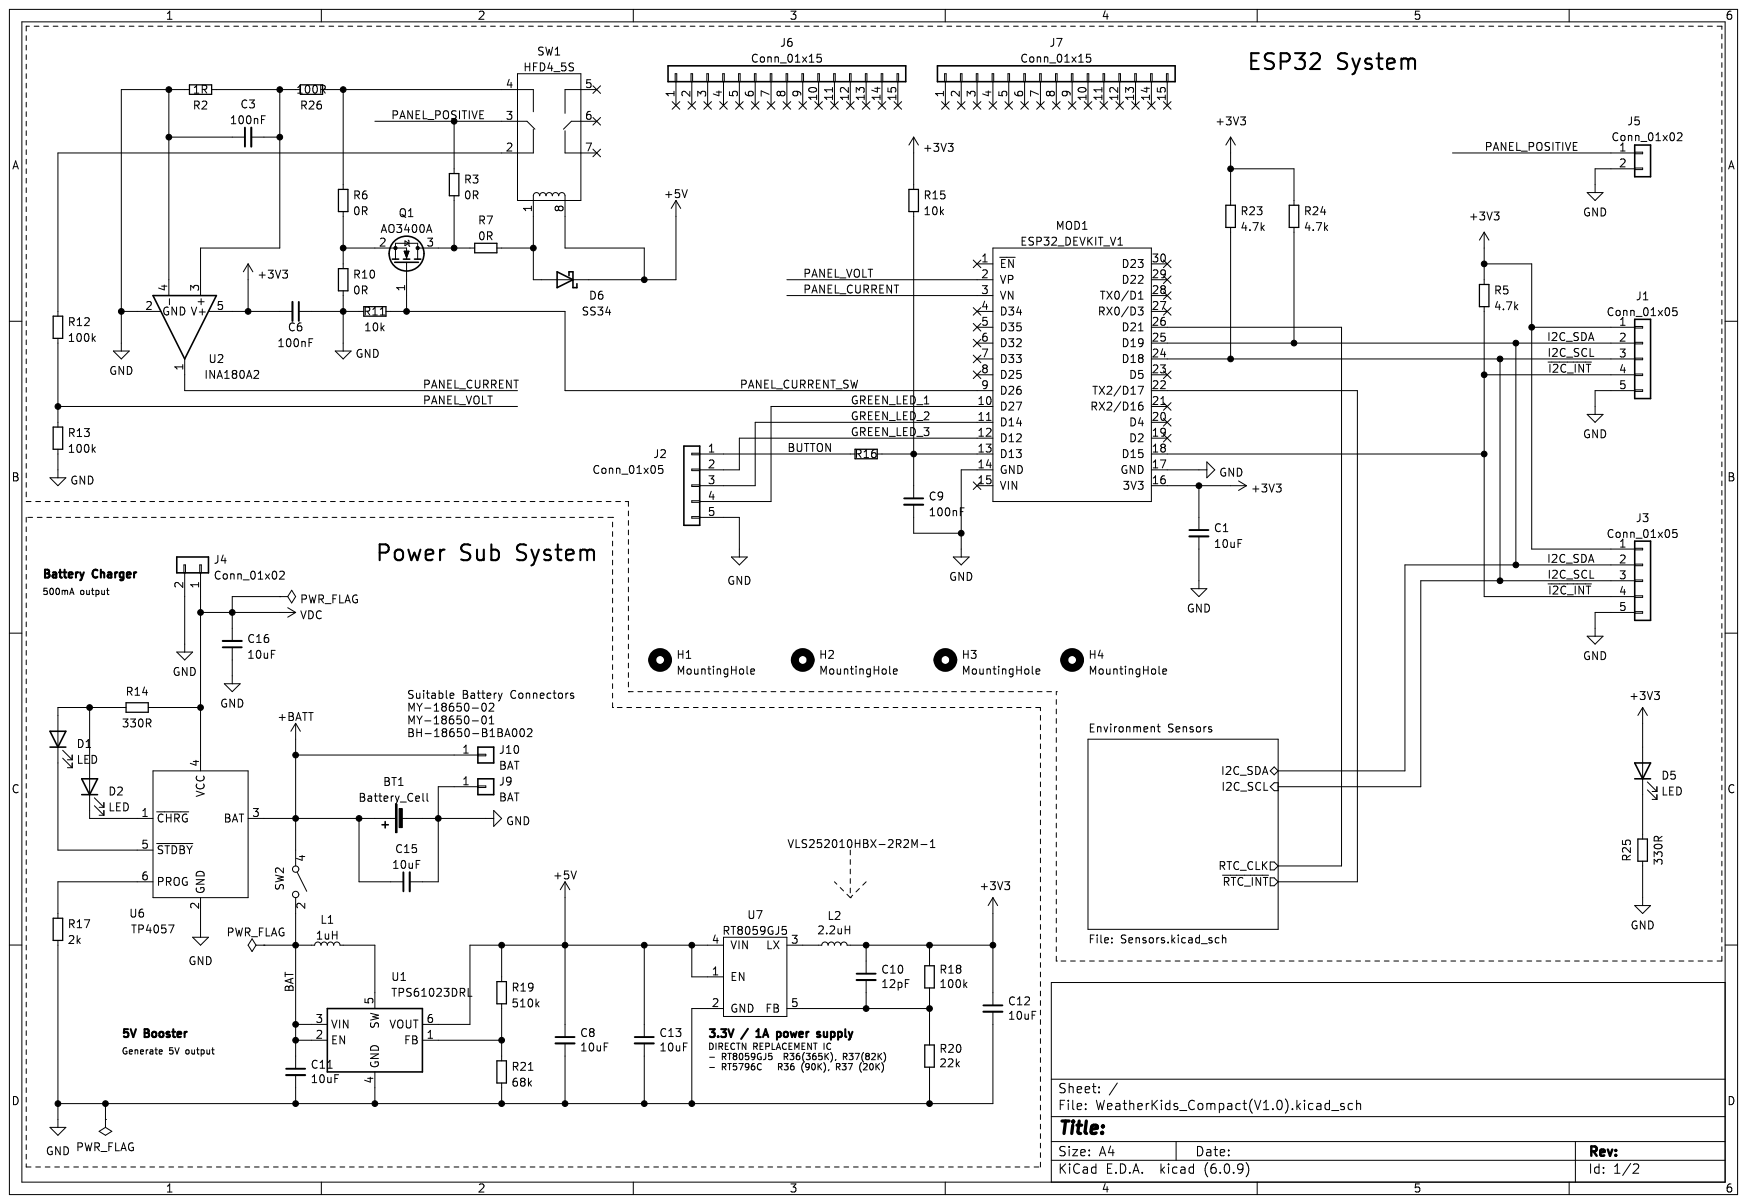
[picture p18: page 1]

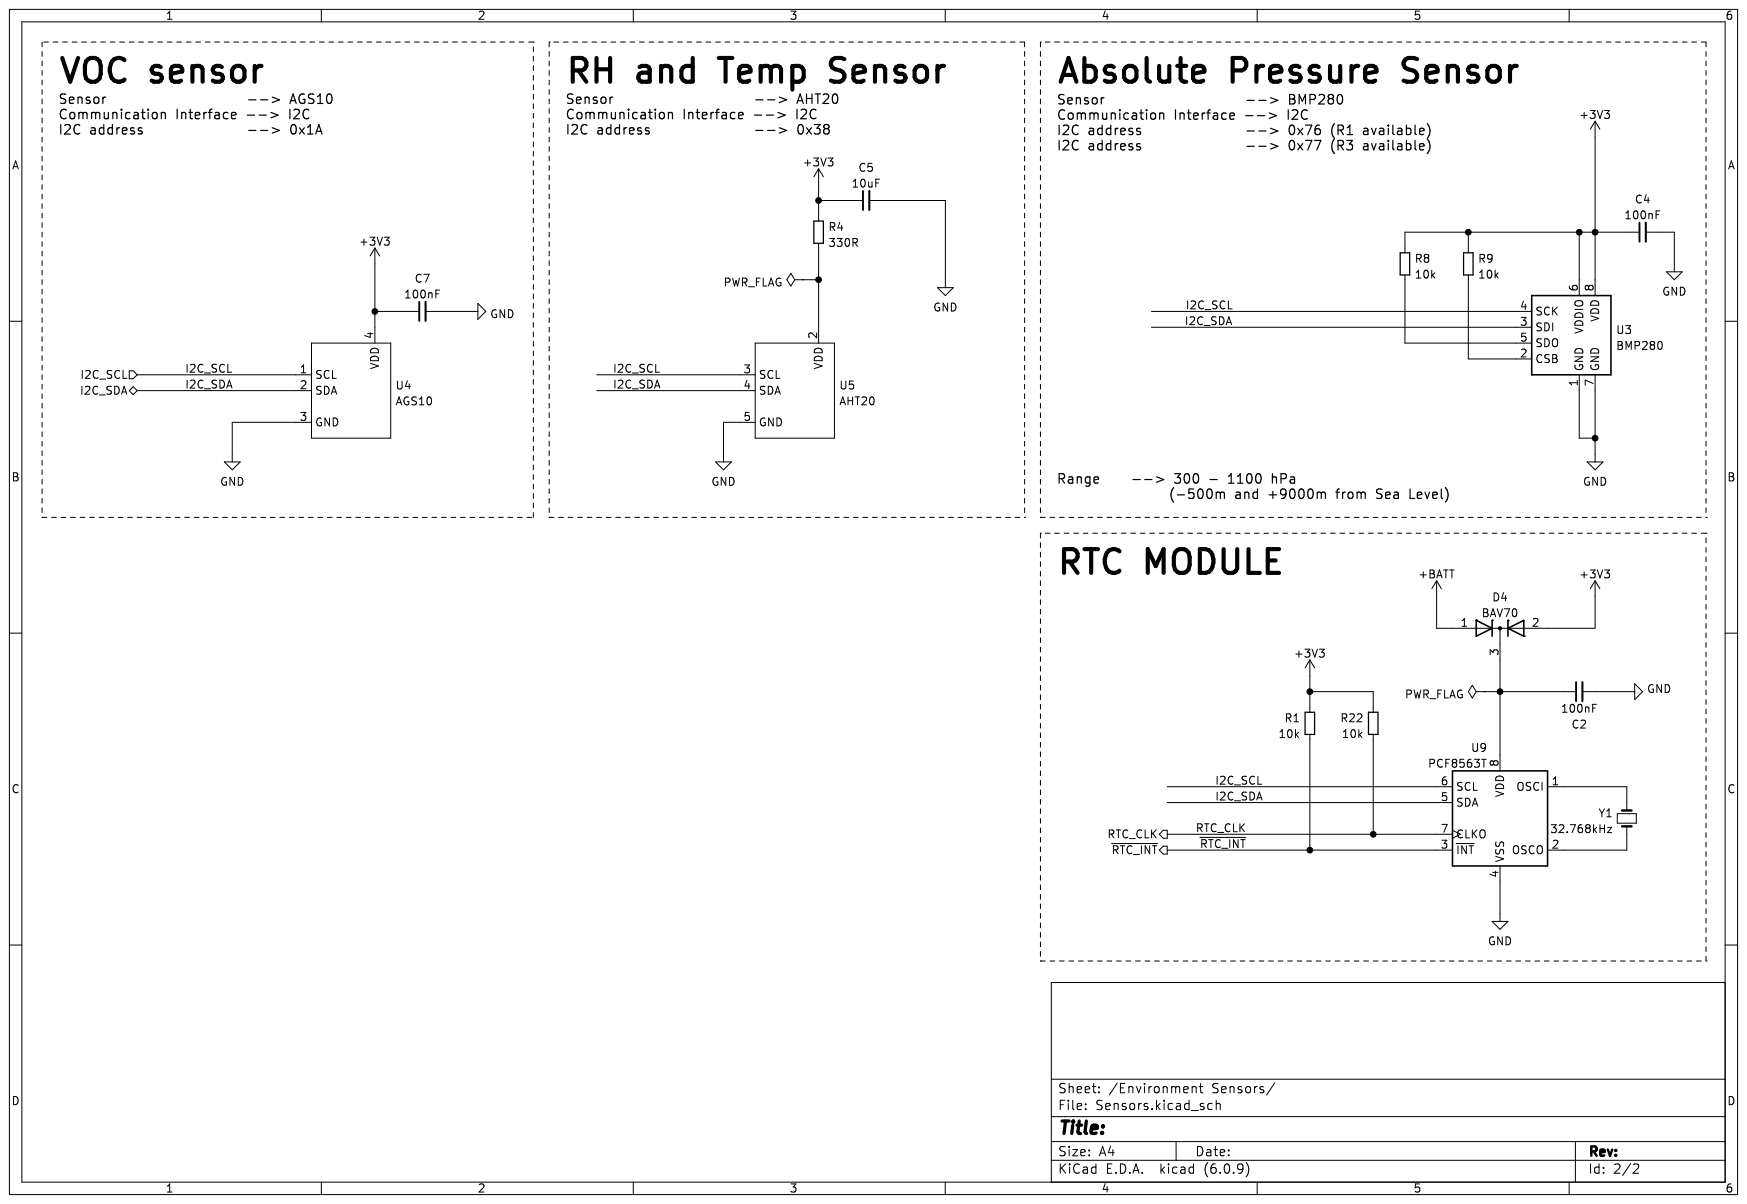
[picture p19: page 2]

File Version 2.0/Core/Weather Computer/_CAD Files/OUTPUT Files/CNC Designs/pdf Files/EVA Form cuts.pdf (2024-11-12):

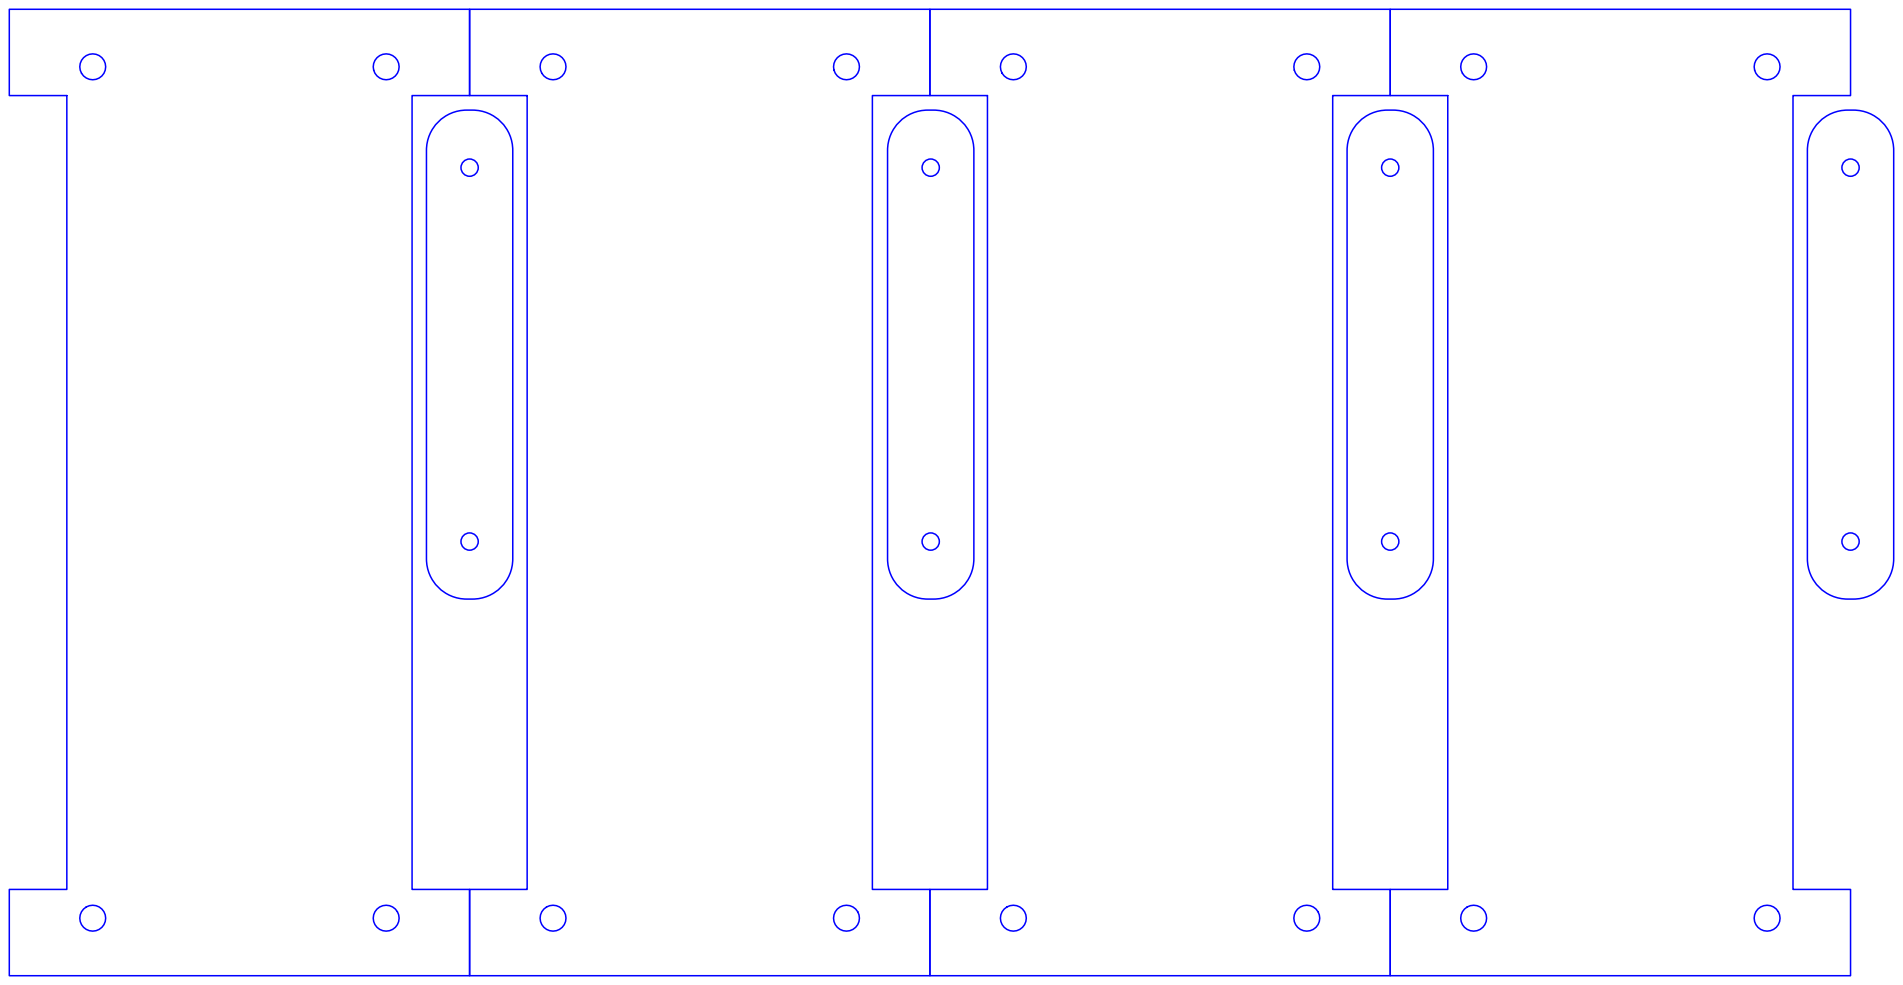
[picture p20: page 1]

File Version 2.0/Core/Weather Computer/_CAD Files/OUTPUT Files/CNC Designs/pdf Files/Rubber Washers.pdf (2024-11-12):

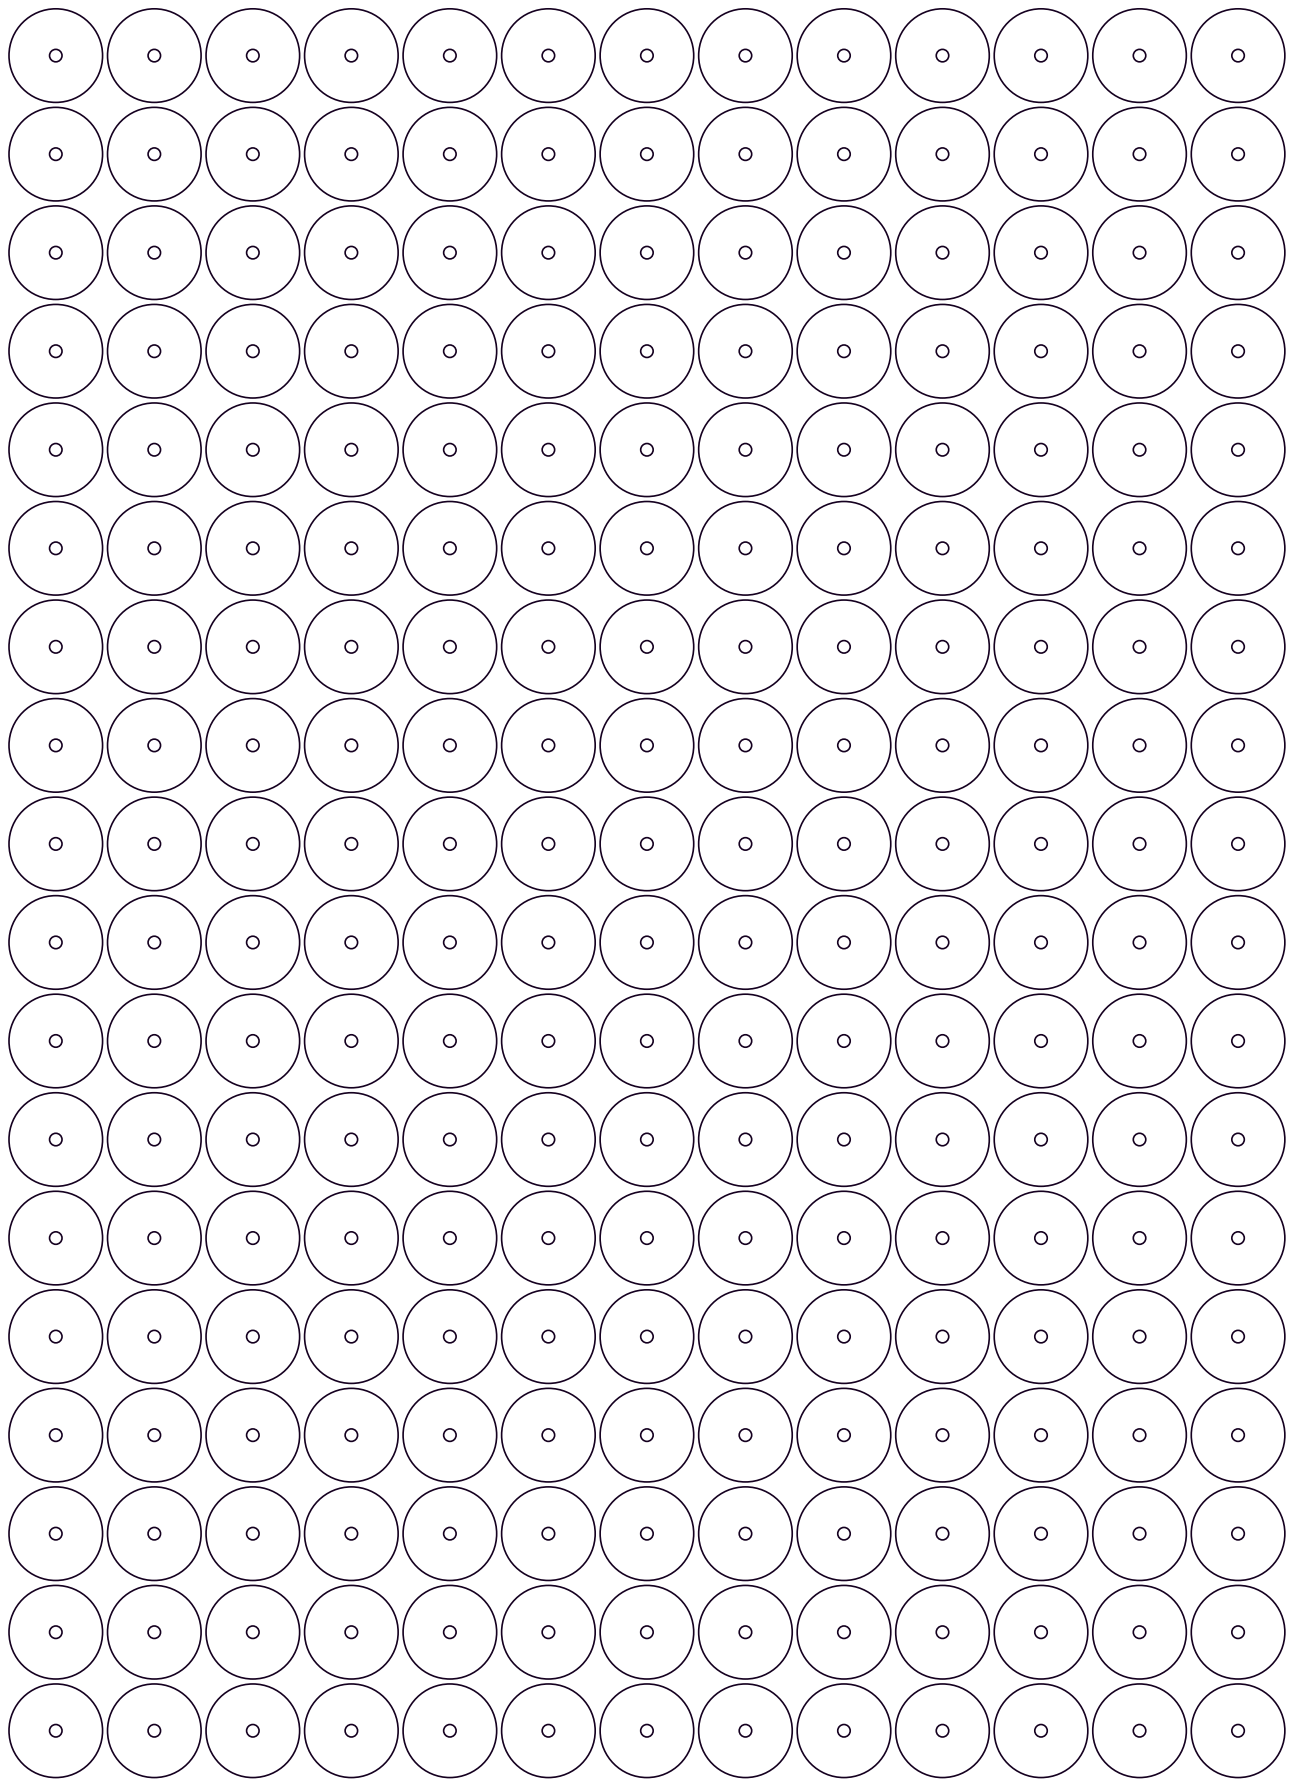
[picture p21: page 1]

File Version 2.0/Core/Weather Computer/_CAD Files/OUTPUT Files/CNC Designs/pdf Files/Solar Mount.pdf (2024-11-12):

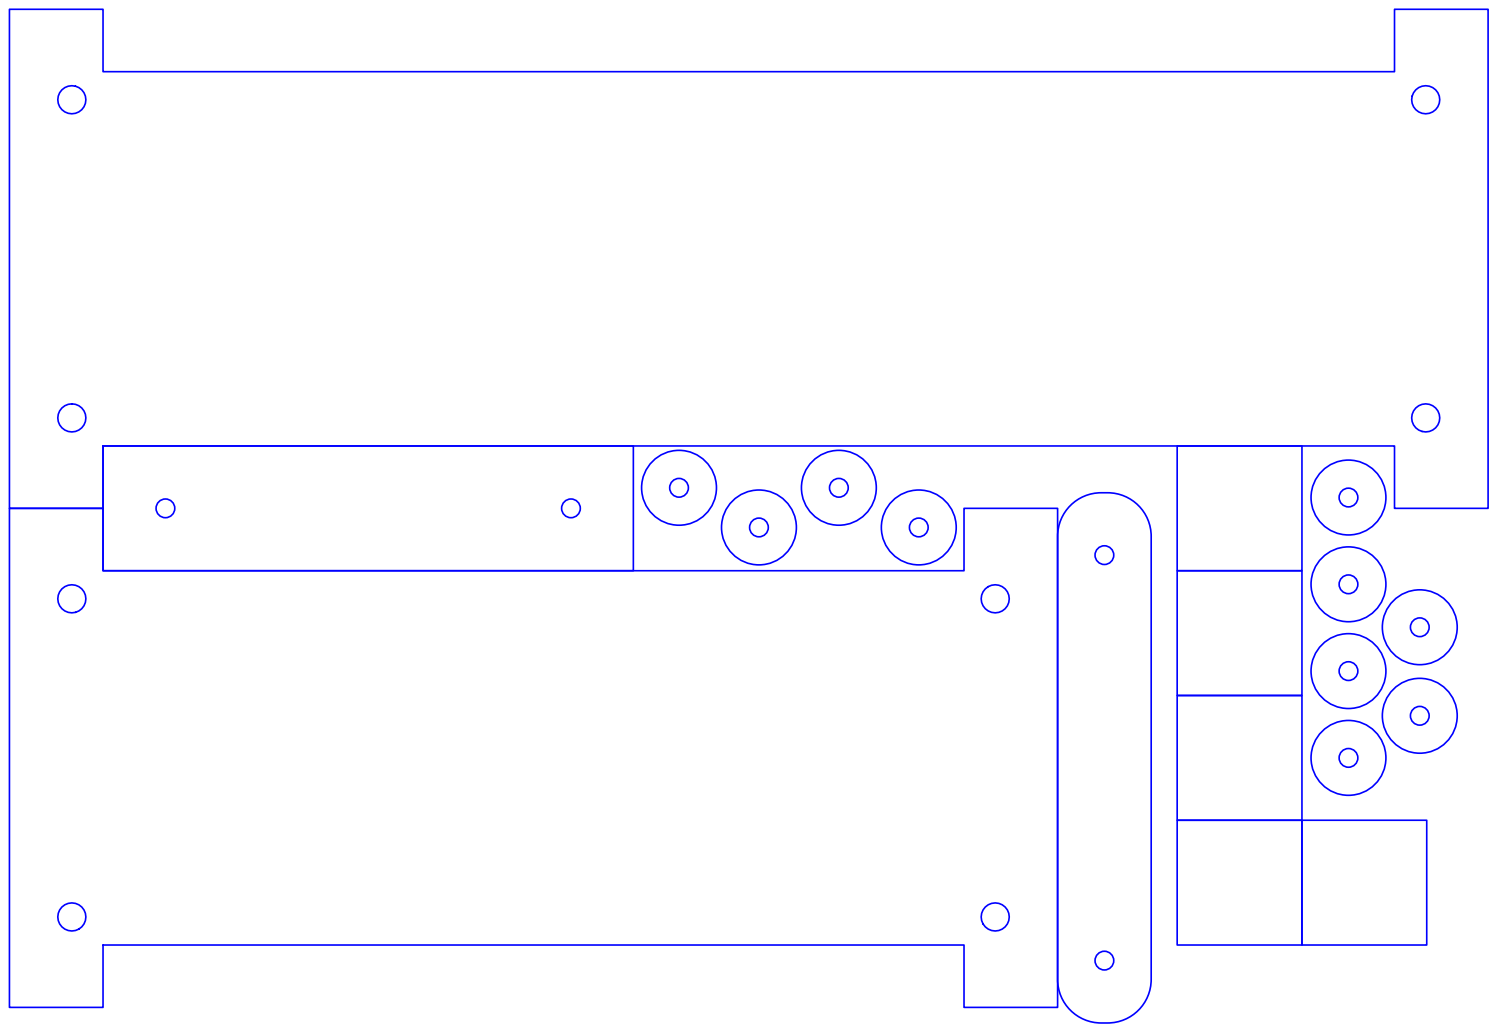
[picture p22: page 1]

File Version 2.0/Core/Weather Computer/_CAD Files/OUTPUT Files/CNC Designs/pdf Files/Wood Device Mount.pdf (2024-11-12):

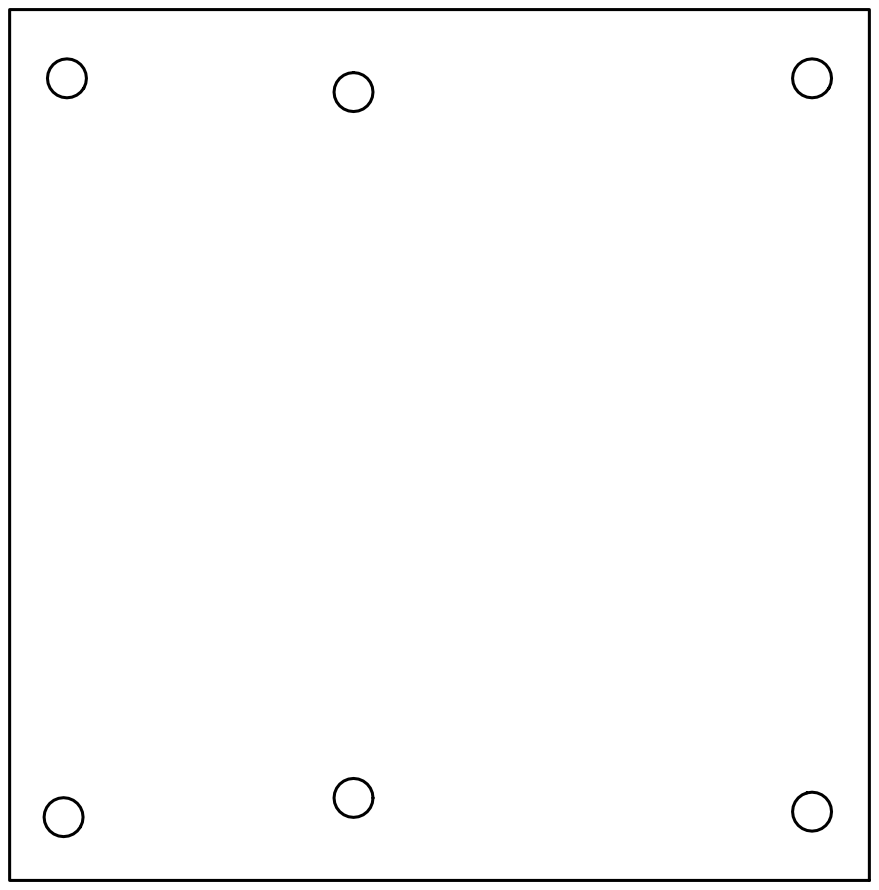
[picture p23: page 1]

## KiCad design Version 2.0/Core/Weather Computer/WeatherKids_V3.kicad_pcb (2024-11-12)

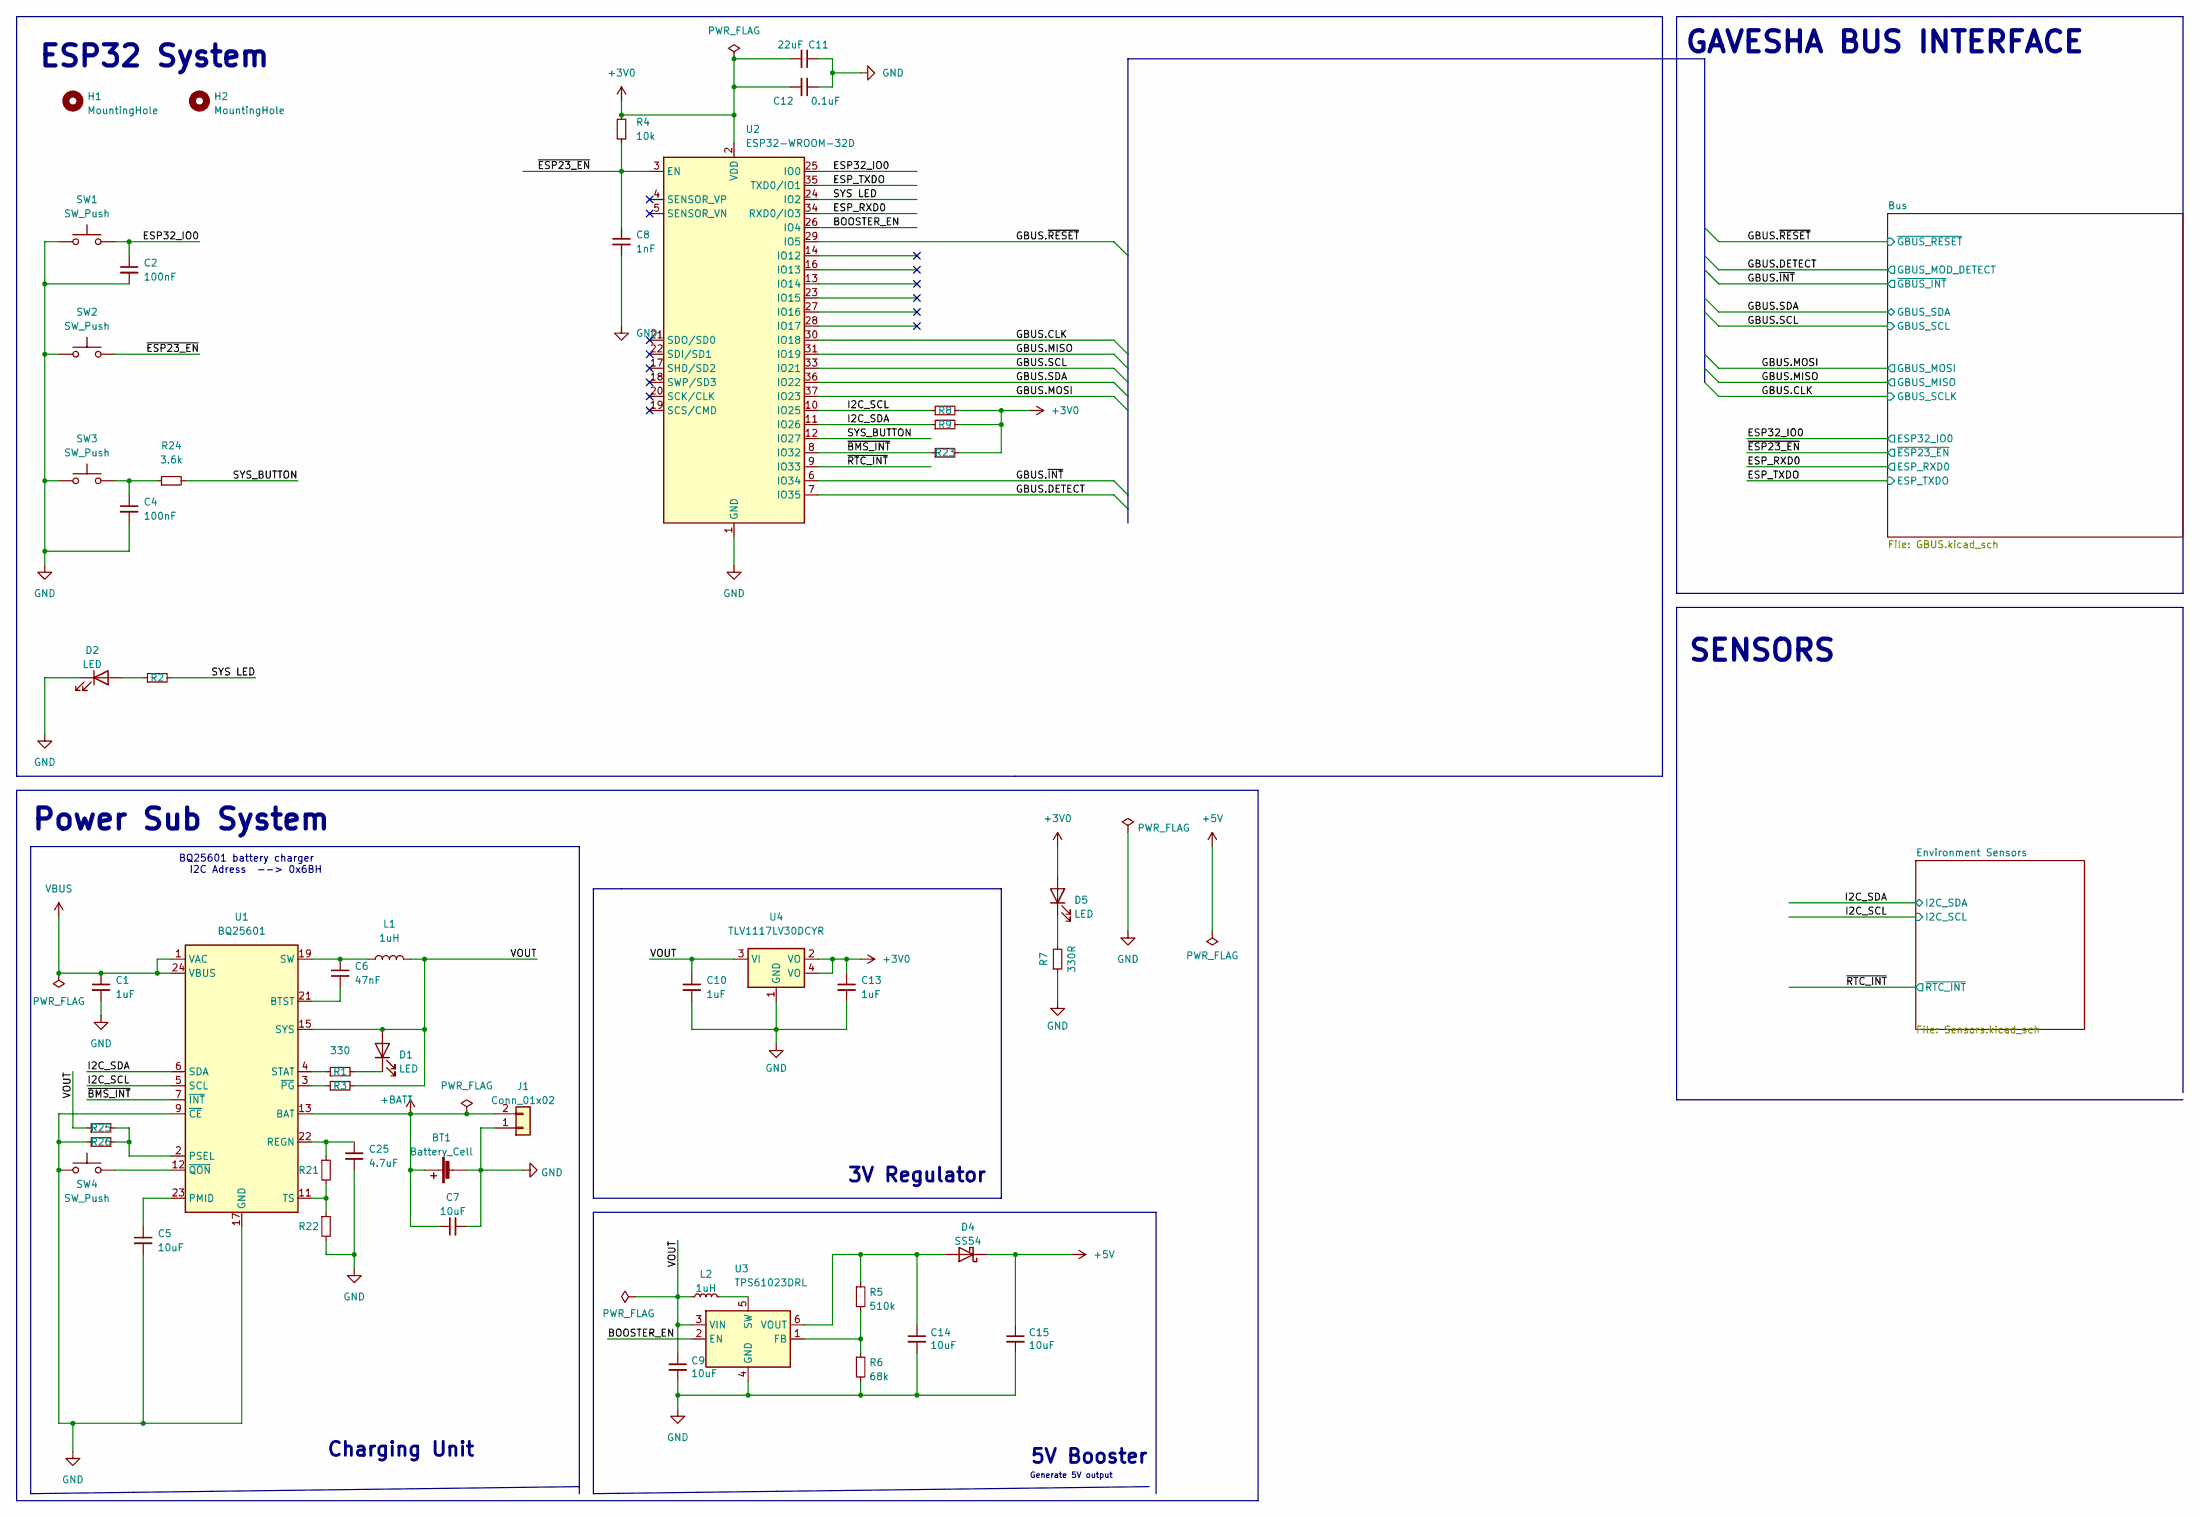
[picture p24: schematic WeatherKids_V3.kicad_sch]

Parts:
BT1: Battery_Cell; BatteryHolder_Keystone_1042_1x18650
C1, C10, C13: 1uF; C_0402_1005Metric
C2, C4: 100nF; C_0402_1005Metric
C5: 10uF; C_0402_1005Metric
C6: 47nF; C_0603_1608Metric
C7, C9, C14, C15: 10uF; C_0805_2012Metric
C8: 1nF; C_0402_1005Metric
C11: 22uF; C_0603_1608Metric
C12: 0.1uF; C_0402_1005Metric
C25: 4.7uF; C_0402_1005Metric
D1, D2, D5: LED; LED_0805_2012Metric
D4: SS54; D_SMA
H1, H2: MountingHole; MountingHole_2.2mm_M2
J1: Conn_01x02; JST_PH_S2B-PH-SM4-TB_1x02-1MP_P2.00mm_Horizontal
L1, L2: 1uH; WPN252010U
R1: 330; R_0402_1005Metric
R2, R7: 330R; R_0402_1005Metric
R3, R4, R8, R9, R21, R22, R23, R25, R26: 10k; R_0402_1005Metric
R5: 510k; R_0402_1005Metric
R6: 68k; R_0402_1005Metric
R24: 3.6k; R_0402_1005Metric
SW1, SW2, SW3, SW4: SW_Push; SKRTLB
U1: BQ25601; Texas_S-PWQFN-N24_EP2.7x2.7mm_ThermalVias
U2: ESP32-WROOM-32D; ESP32-WROOM-32
U3: TPS61023DRL; DRL0006A
U4: TLV1117LV30DCYR; SOT-223

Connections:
+3V0: C11.2, C12.2, C13.1, D5.2 (A), R4.1, R8.2, R9.2, R23.2, U2.2 (VDD), U4.2 (VO), U4.4 (VO); also elsewhere on the board
+5V: C15.1, D4.1 (K); also elsewhere on the board
+BATT: BT1.1 (+), C7.1, J1.2, U1.13 (BAT), U1.14 (BAT); also elsewhere on the board
/BOOSTER_EN: U2.26 (IO4), U3.2 (EN)
/ESP32_IO0: C2.1, SW1.2, U2.25 (IO0); also elsewhere on the board
/ESP_RXD0: U2.34 (RXD0/IO3); also elsewhere on the board
/ESP_TXDO: U2.35 (TXD0/IO1); also elsewhere on the board
/GBUS.CLK: U2.30 (IO18); also elsewhere on the board
/GBUS.DETECT: U2.7 (IO35); also elsewhere on the board
/GBUS.MISO: U2.31 (IO19); also elsewhere on the board
/GBUS.MOSI: U2.37 (IO23); also elsewhere on the board
/GBUS.SCL: U2.33 (IO21); also elsewhere on the board
/GBUS.SDA: U2.36 (IO22); also elsewhere on the board
/GBUS.~INT: U2.6 (IO34); also elsewhere on the board
/GBUS.~RESET: U2.29 (IO5); also elsewhere on the board
/I2C_SCL: R8.1, U1.5 (SCL), U2.10 (IO25); also elsewhere on the board
/I2C_SDA: R9.1, U1.6 (SDA), U2.11 (IO26); also elsewhere on the board
/SYS LED: R2.2, U2.24 (IO2)
/SYS_BUTTON: R24.2, U2.12 (IO27)
/VOUT: C9.1, C10.1, D1.2 (A), L1.2, L2.1, R3.2, R25.1, U1.15 (SYS), U1.16 (SYS), U3.3 (VIN), U4.3 (VI)
/~BMS_INT: R23.1, U1.7 (~INT), U2.8 (IO32)
/~ESP23_EN: C8.1, R4.2, SW2.2, U2.3 (EN); also elsewhere on the board
/~RTC_INT: U2.9 (IO33); also elsewhere on the board
GND: BT1.2 (-), C1.2, C2.2, C4.2, C5.2, C7.2, C8.2, C9.2, C10.2, C11.1, C12.1, C13.2, C14.2, C15.2, C25.2, D2.1 (K), J1.1, R6.2, R7.1, R22.2, R26.1, SW1.1, SW2.1, SW3.1, SW4.1, U1.9 (~CE), U1.17 (GND), U1.18 (GND), U1.25 (GND), U2.1 (GND), U2.15 (GND), U2.38 (GND), U2.39 (GND), U3.4 (GND), U4.1 (GND); also elsewhere on the board
unnamed: C4.1, R24.1, SW3.2
unnamed: C5.1, U1.23 (PMID)
unnamed: C6.1, L1.1, U1.19 (SW), U1.20 (SW)
unnamed: C6.2, U1.21 (BTST)
unnamed: C14.1, D4.2 (A), R5.1, U3.6 (VOUT)
unnamed: C25.1, R21.1, U1.22 (REGN)
unnamed: D1.1 (K), R1.2
unnamed: D2.2 (A), R2.1
unnamed: D5.1 (K), R7.2
unnamed: L2.2, U3.5 (SW)
unnamed: R1.1, U1.4 (STAT)
unnamed: R3.1, U1.3 (~PG)
unnamed: R5.2, R6.1, U3.1 (FB)
unnamed: R21.2, R22.1, U1.11 (TS)
unnamed: R25.2, R26.2, U1.2 (PSEL)
unnamed: SW4.2, U1.12 (~QON)
VBUS: C1.1, U1.1 (VAC), U1.24 (VBUS); also elsewhere on the board

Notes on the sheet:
5V Booster
SENSORS
Power Sub System
ESP32 System
3V Regulator
BQ25601 battery charger I2C Adress --> 0x6BH
Charging Unit
Generate 5V output
GAVESHA BUS INTERFACE

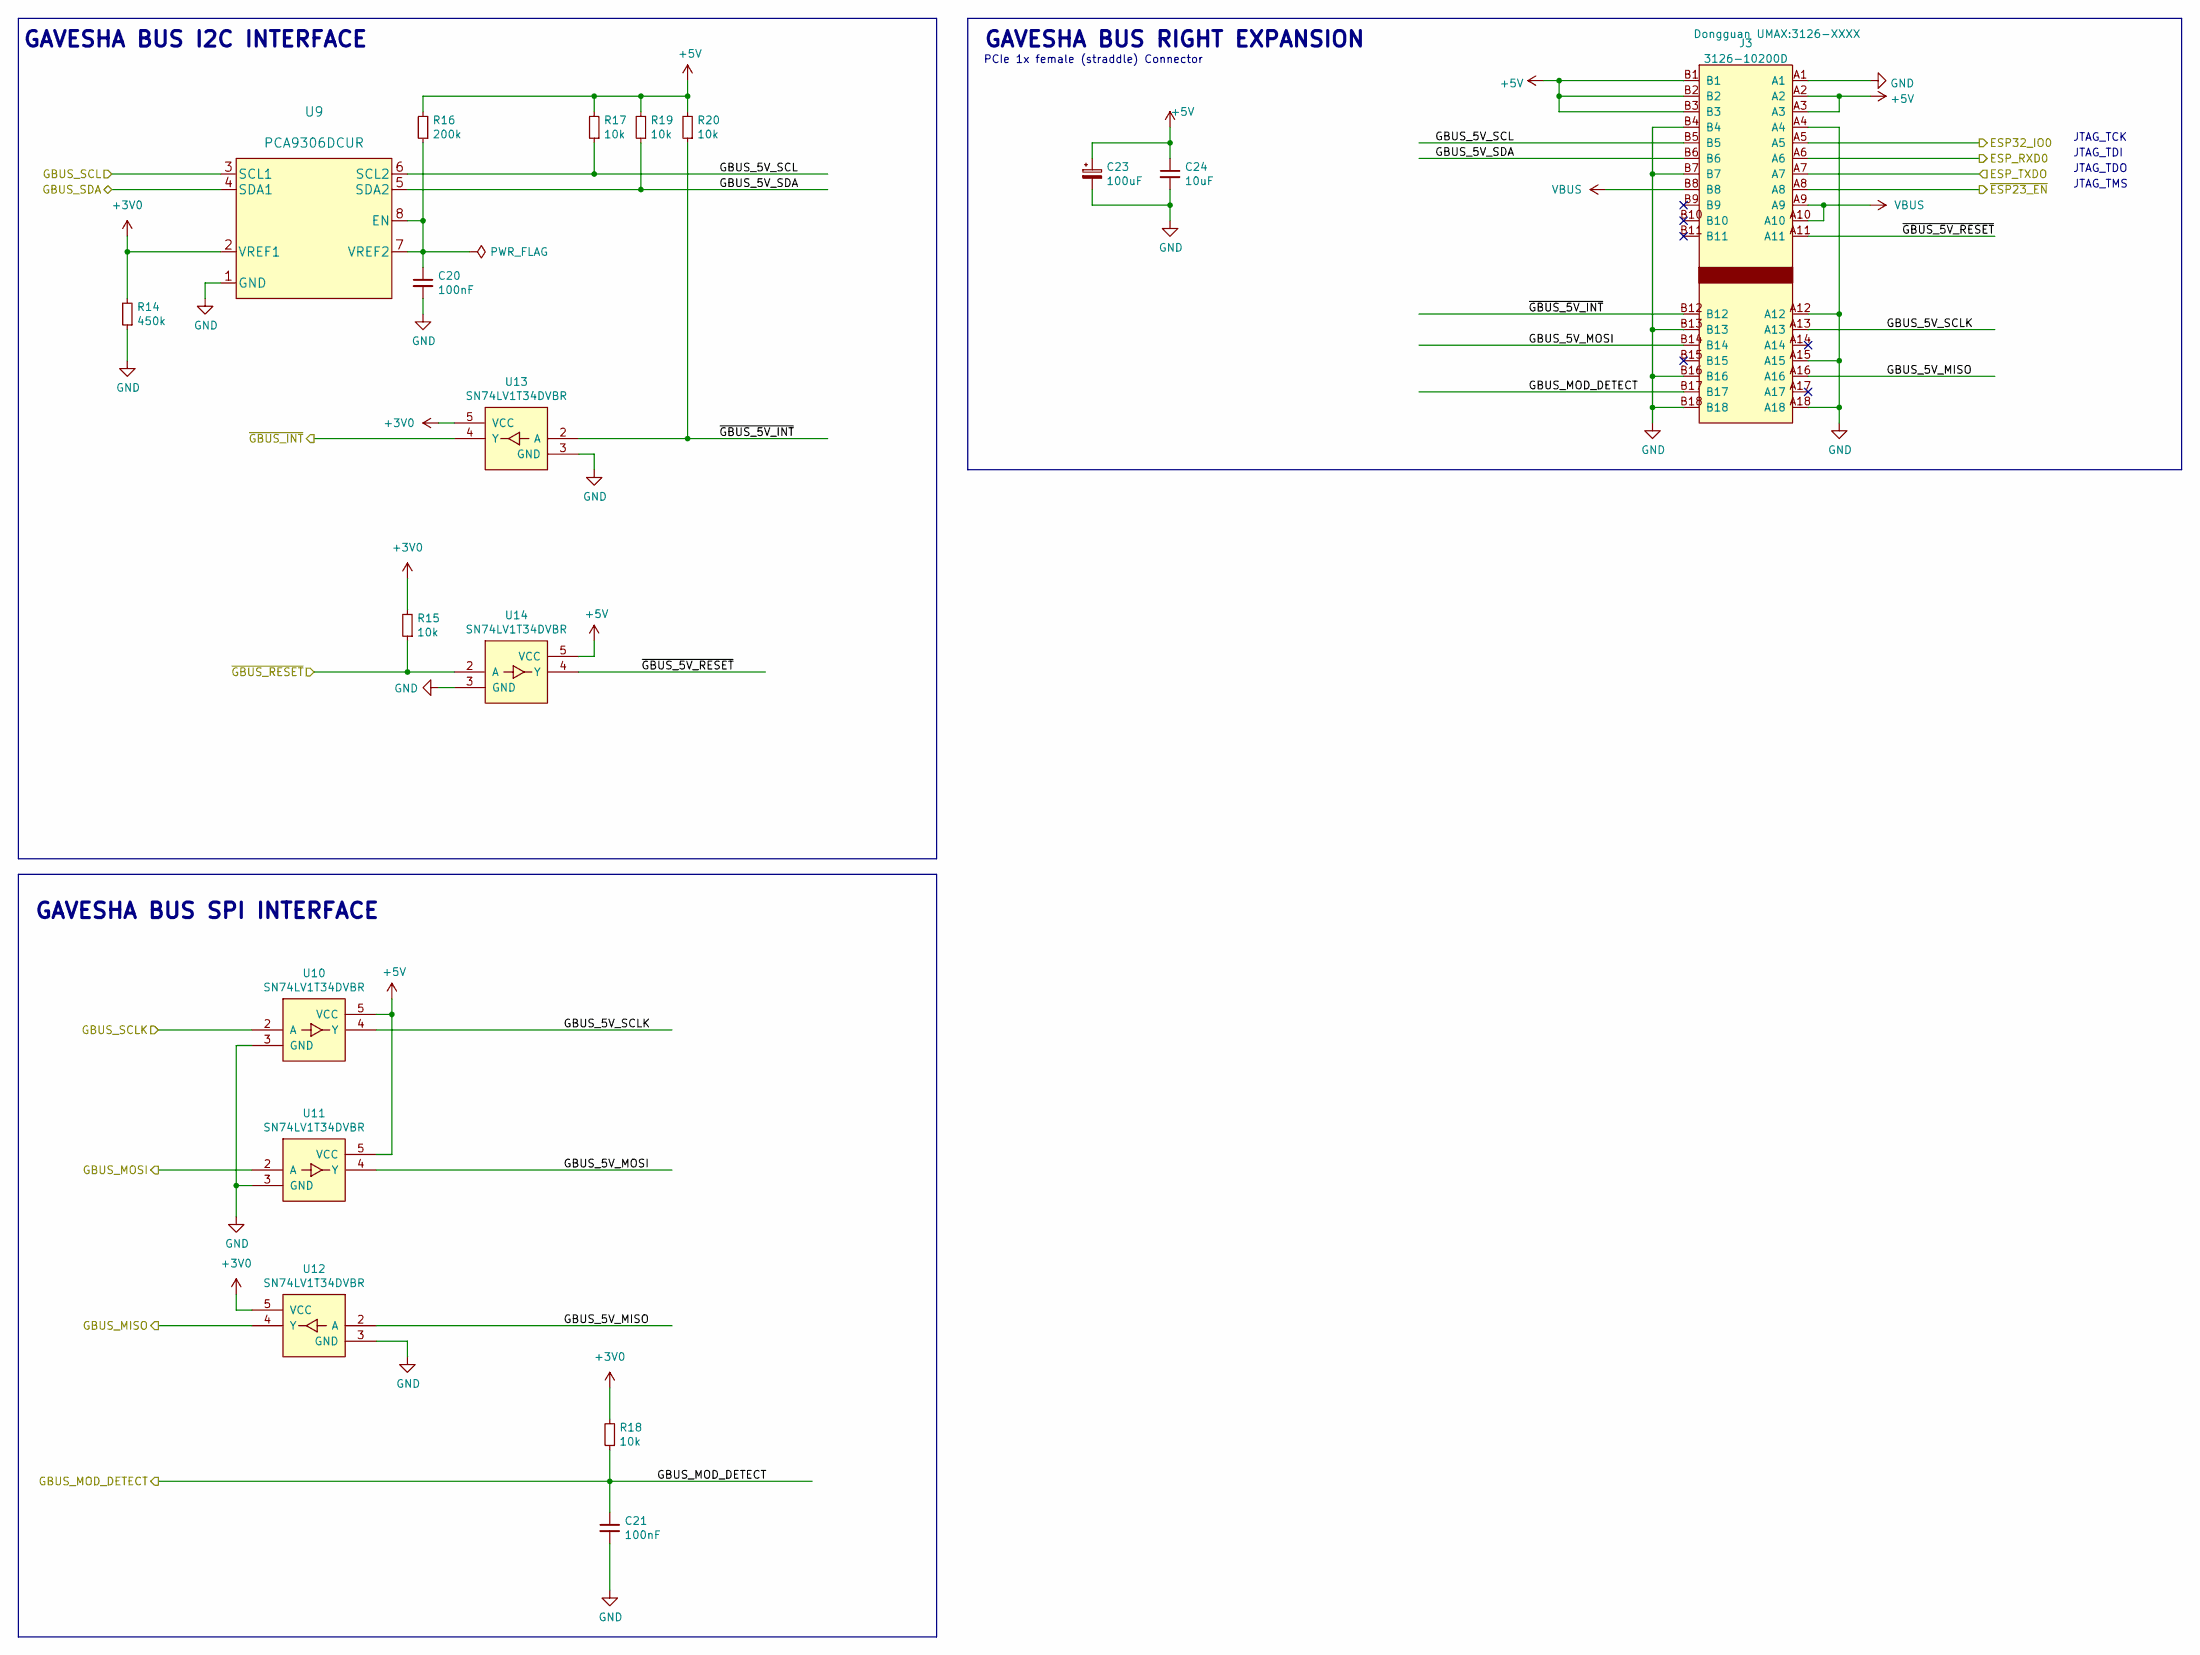
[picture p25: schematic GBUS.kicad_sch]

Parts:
C20, C21: 100nF; C_0402_1005Metric
C23: 100uF; CP_EIA-3528-12_Kemet-T
C24: 10uF; C_0805_2012Metric
J3: 3126-10200D; 3126-XXXX
R14: 450k; R_0402_1005Metric
R15, R17, R18, R19, R20: 10k; R_0402_1005Metric
R16: 200k; R_0402_1005Metric
U9: PCA9306DCUR
U10, U11, U12, U13, U14: SN74LV1T34DVBR; SOT-23-5

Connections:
+3V0: R14.2, R15.2, R18.2, U9.2 (VREF1), U12.5 (VCC), U13.5 (VCC); also elsewhere on the board
+5V: C23.1, C24.1, J3.A2, J3.A3, J3.B1, J3.B2, J3.B3, R16.2, R17.2, R19.2, R20.2, U10.5 (VCC), U11.5 (VCC), U14.5 (VCC); also elsewhere on the board
/Bus/GBUS_5V_MISO: J3.A16, U12.2 (A)
/Bus/GBUS_5V_MOSI: J3.B14, U11.4 (Y)
/Bus/GBUS_5V_SCL: J3.B5, R17.1, U9.6 (SCL2)
/Bus/GBUS_5V_SCLK: J3.A13, U10.4 (Y)
/Bus/GBUS_5V_SDA: J3.B6, R19.1, U9.5 (SDA2)
/Bus/~GBUS_5V_INT: J3.B12, R20.1, U13.2 (A)
/Bus/~GBUS_5V_RESET: J3.A11, U14.4 (Y)
/ESP32_IO0: J3.A5; also elsewhere on the board
/ESP_RXD0: J3.A6; also elsewhere on the board
/ESP_TXDO: J3.A7; also elsewhere on the board
/GBUS.CLK: U10.2 (A); also elsewhere on the board
/GBUS.DETECT: C21.1, J3.B17, R18.1; also elsewhere on the board
/GBUS.MISO: U12.4 (Y); also elsewhere on the board
/GBUS.MOSI: U11.2 (A); also elsewhere on the board
/GBUS.SCL: U9.3 (SCL1); also elsewhere on the board
/GBUS.SDA: U9.4 (SDA1); also elsewhere on the board
/GBUS.~INT: U13.4 (Y); also elsewhere on the board
/GBUS.~RESET: R15.1, U14.2 (A); also elsewhere on the board
/~ESP23_EN: J3.A8; also elsewhere on the board
GND: C20.2, C21.2, C23.2, C24.2, J3.A1, J3.A4, J3.A12, J3.A15, J3.A18, J3.B4, J3.B7, J3.B13, J3.B16, J3.B18, R14.1, U9.1 (GND), U10.3 (GND), U11.3 (GND), U12.3 (GND), U13.3 (GND), U14.3 (GND); also elsewhere on the board
unnamed: C20.1, R16.1, U9.7 (VREF2), U9.8 (EN)
VBUS: J3.A9, J3.A10, J3.B8; also elsewhere on the board

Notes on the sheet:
GAVESHA BUS I2C INTERFACE
JTAG_TDO
GAVESHA BUS SPI INTERFACE
JTAG_TDI
JTAG_TCK
PCIe 1x female (straddle) Connector
GAVESHA BUS RIGHT EXPANSION
JTAG_TMS

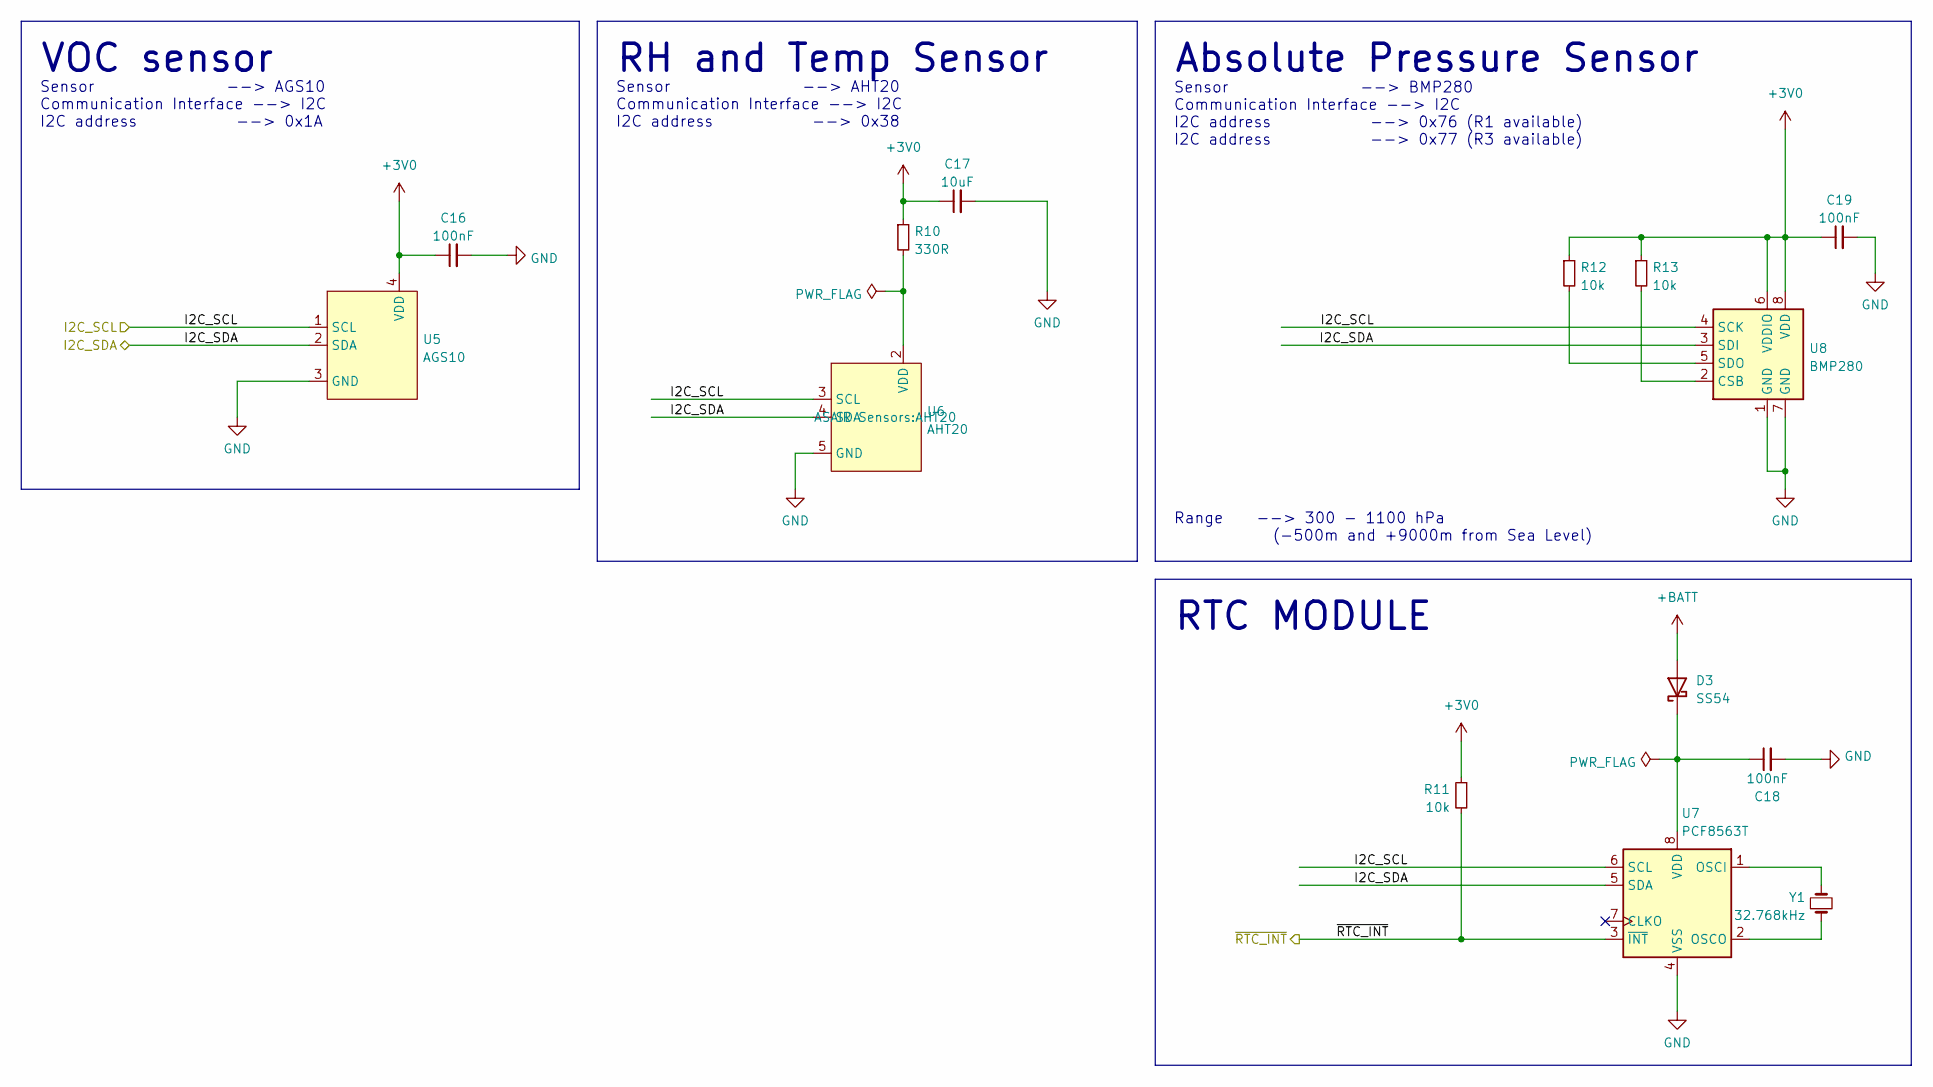
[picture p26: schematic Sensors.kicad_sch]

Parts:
C16, C18, C19: 100nF; C_0402_1005Metric
C17: 10uF; C_0805_2012Metric
D3: SS54; D_SOD-323; part no C2128
R10: 330R; R_0402_1005Metric
R11, R12, R13: 10k; R_0402_1005Metric
U5: AGS10
U6: AHT20
U7: PCF8563T; SOIC-8_3.9x4.9mm_P1.27mm
U8: BMP280; Bosch_LGA-8_2x2.5mm_P0.65mm_ClockwisePinNumbering
Y1: 32.768kHz; Crystal_SMD_3215-2Pin_3.2x1.5mm

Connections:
+3V0: C16.1, C17.1, C19.1, R10.1, R11.1, R12.1, R13.1, U5.4 (VDD), U8.6 (VDDIO), U8.8 (VDD); also elsewhere on the board
+BATT: D3.2 (A); also elsewhere on the board
/I2C_SCL: U5.1 (SCL), U6.3 (SCL), U7.6 (SCL), U8.4 (SCK); also elsewhere on the board
/I2C_SDA: U5.2 (SDA), U6.4 (SDA), U7.5 (SDA), U8.3 (SDI); also elsewhere on the board
/~RTC_INT: R11.2, U7.3 (~INT); also elsewhere on the board
GND: C16.2, C17.2, C18.2, C19.2, U5.3 (GND), U6.5 (GND), U7.4 (VSS), U8.1 (GND), U8.7 (GND); also elsewhere on the board
unnamed: C18.1, D3.1 (K), U7.8 (VDD)
unnamed: R10.2, U6.2 (VDD)
unnamed: R12.2, U8.5 (SDO)
unnamed: R13.2, U8.2 (CSB)
unnamed: U7.1 (OSCI), Y1.2
unnamed: U7.2 (OSCO), Y1.1

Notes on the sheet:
Sensor --> AGS10 Communication Interface --> I2C I2C address --> 0x1A
Sensor --> BMP280 Communication Interface --> I2C I2C address --> 0x76 (R1 available) I2C address --> 0x77 (R3 available)
Range --> 300 - 1100 hPa (-500m and +9000m from Sea Level)
RH and Temp Sensor
RTC MODULE
Sensor --> AHT20 Communication Interface --> I2C I2C address --> 0x38
VOC sensor
Absolute Pressure Sensor

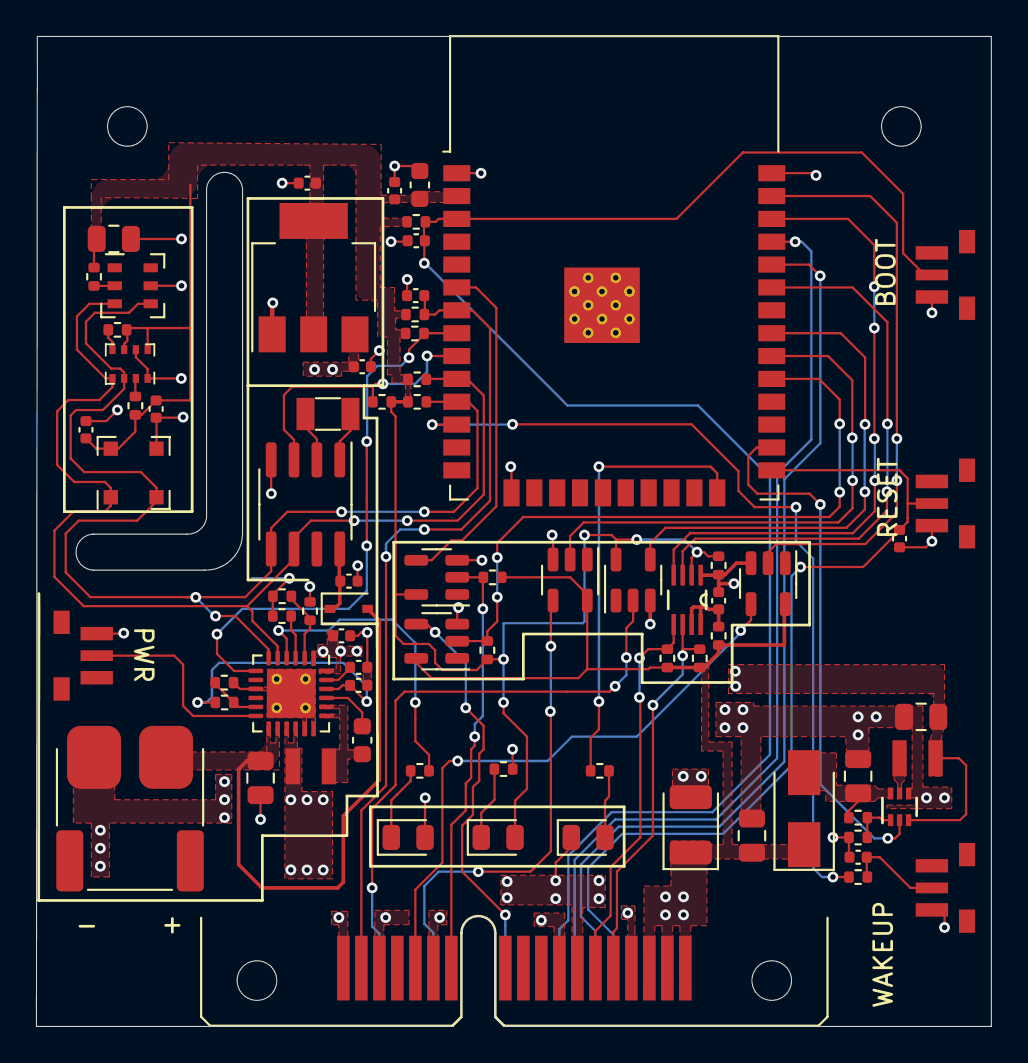
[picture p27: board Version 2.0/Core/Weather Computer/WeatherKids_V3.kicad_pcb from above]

Board: 2 copper layers, 53.0 x 55.0 mm, 78 parts (0 on the bottom side), 55 nets.

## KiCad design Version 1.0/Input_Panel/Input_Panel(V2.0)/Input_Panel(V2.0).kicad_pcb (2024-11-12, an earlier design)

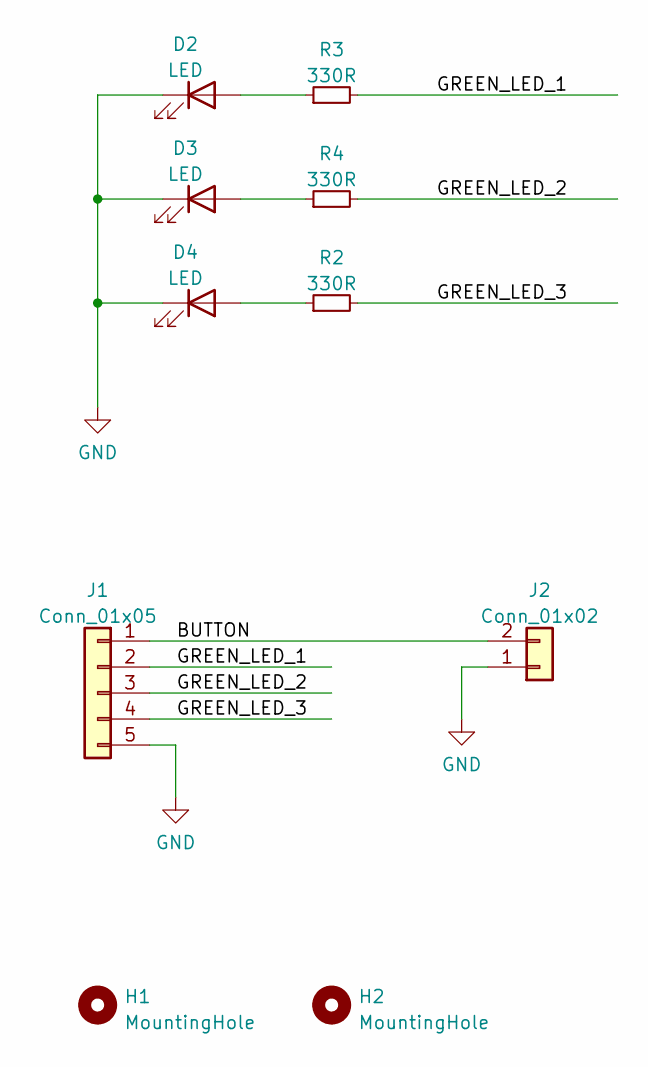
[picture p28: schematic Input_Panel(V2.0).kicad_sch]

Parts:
D2, D3, D4: LED; LED_D5.0mm
H1, H2: MountingHole; MountingHole_3.2mm_M3
J1: Conn_01x05; JST_PH_B5B-PH-K_1x05_P2.00mm_Vertical
J2: Conn_01x02; JST_PH_B2B-PH-K_1x02_P2.00mm_Vertical
R2, R3, R4: 330R; R_Axial_DIN0207_L6.3mm_D2.5mm_P10.16mm_Horizontal

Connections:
/BUTTON: J1.1, J2.2
/GREEN_LED_1: J1.2, R3.2
/GREEN_LED_2: J1.3, R4.2
/GREEN_LED_3: J1.4, R2.2
GND: D2.1 (K), D3.1 (K), D4.1 (K), J1.5, J2.1
unnamed: D2.2 (A), R3.1
unnamed: D3.2 (A), R4.1
unnamed: D4.2 (A), R2.1

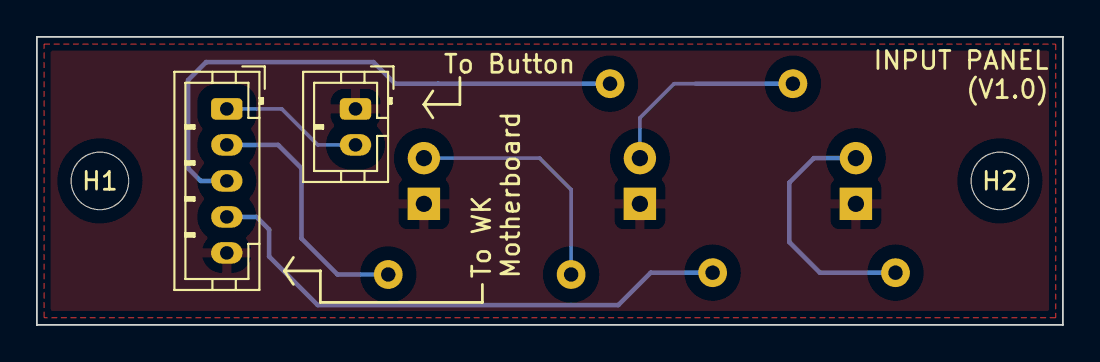
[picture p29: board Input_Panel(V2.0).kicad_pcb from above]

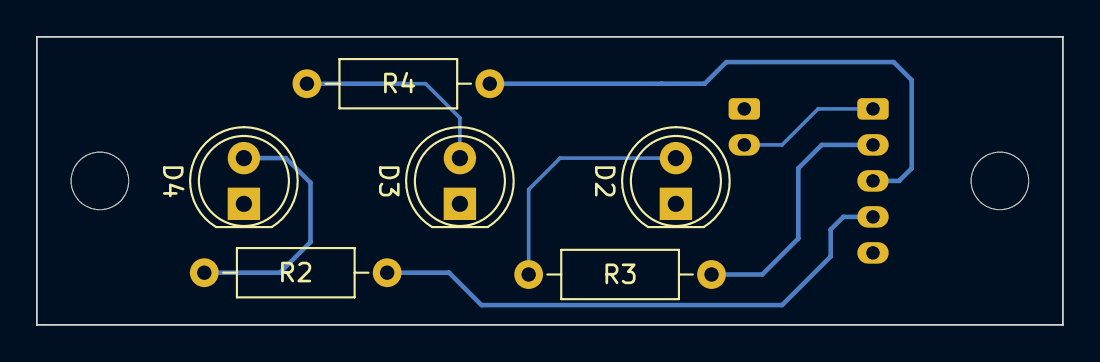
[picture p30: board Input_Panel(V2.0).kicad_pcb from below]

Board: 2 copper layers, 57.0 x 16.0 mm, 10 parts (6 on the bottom side), 8 nets.

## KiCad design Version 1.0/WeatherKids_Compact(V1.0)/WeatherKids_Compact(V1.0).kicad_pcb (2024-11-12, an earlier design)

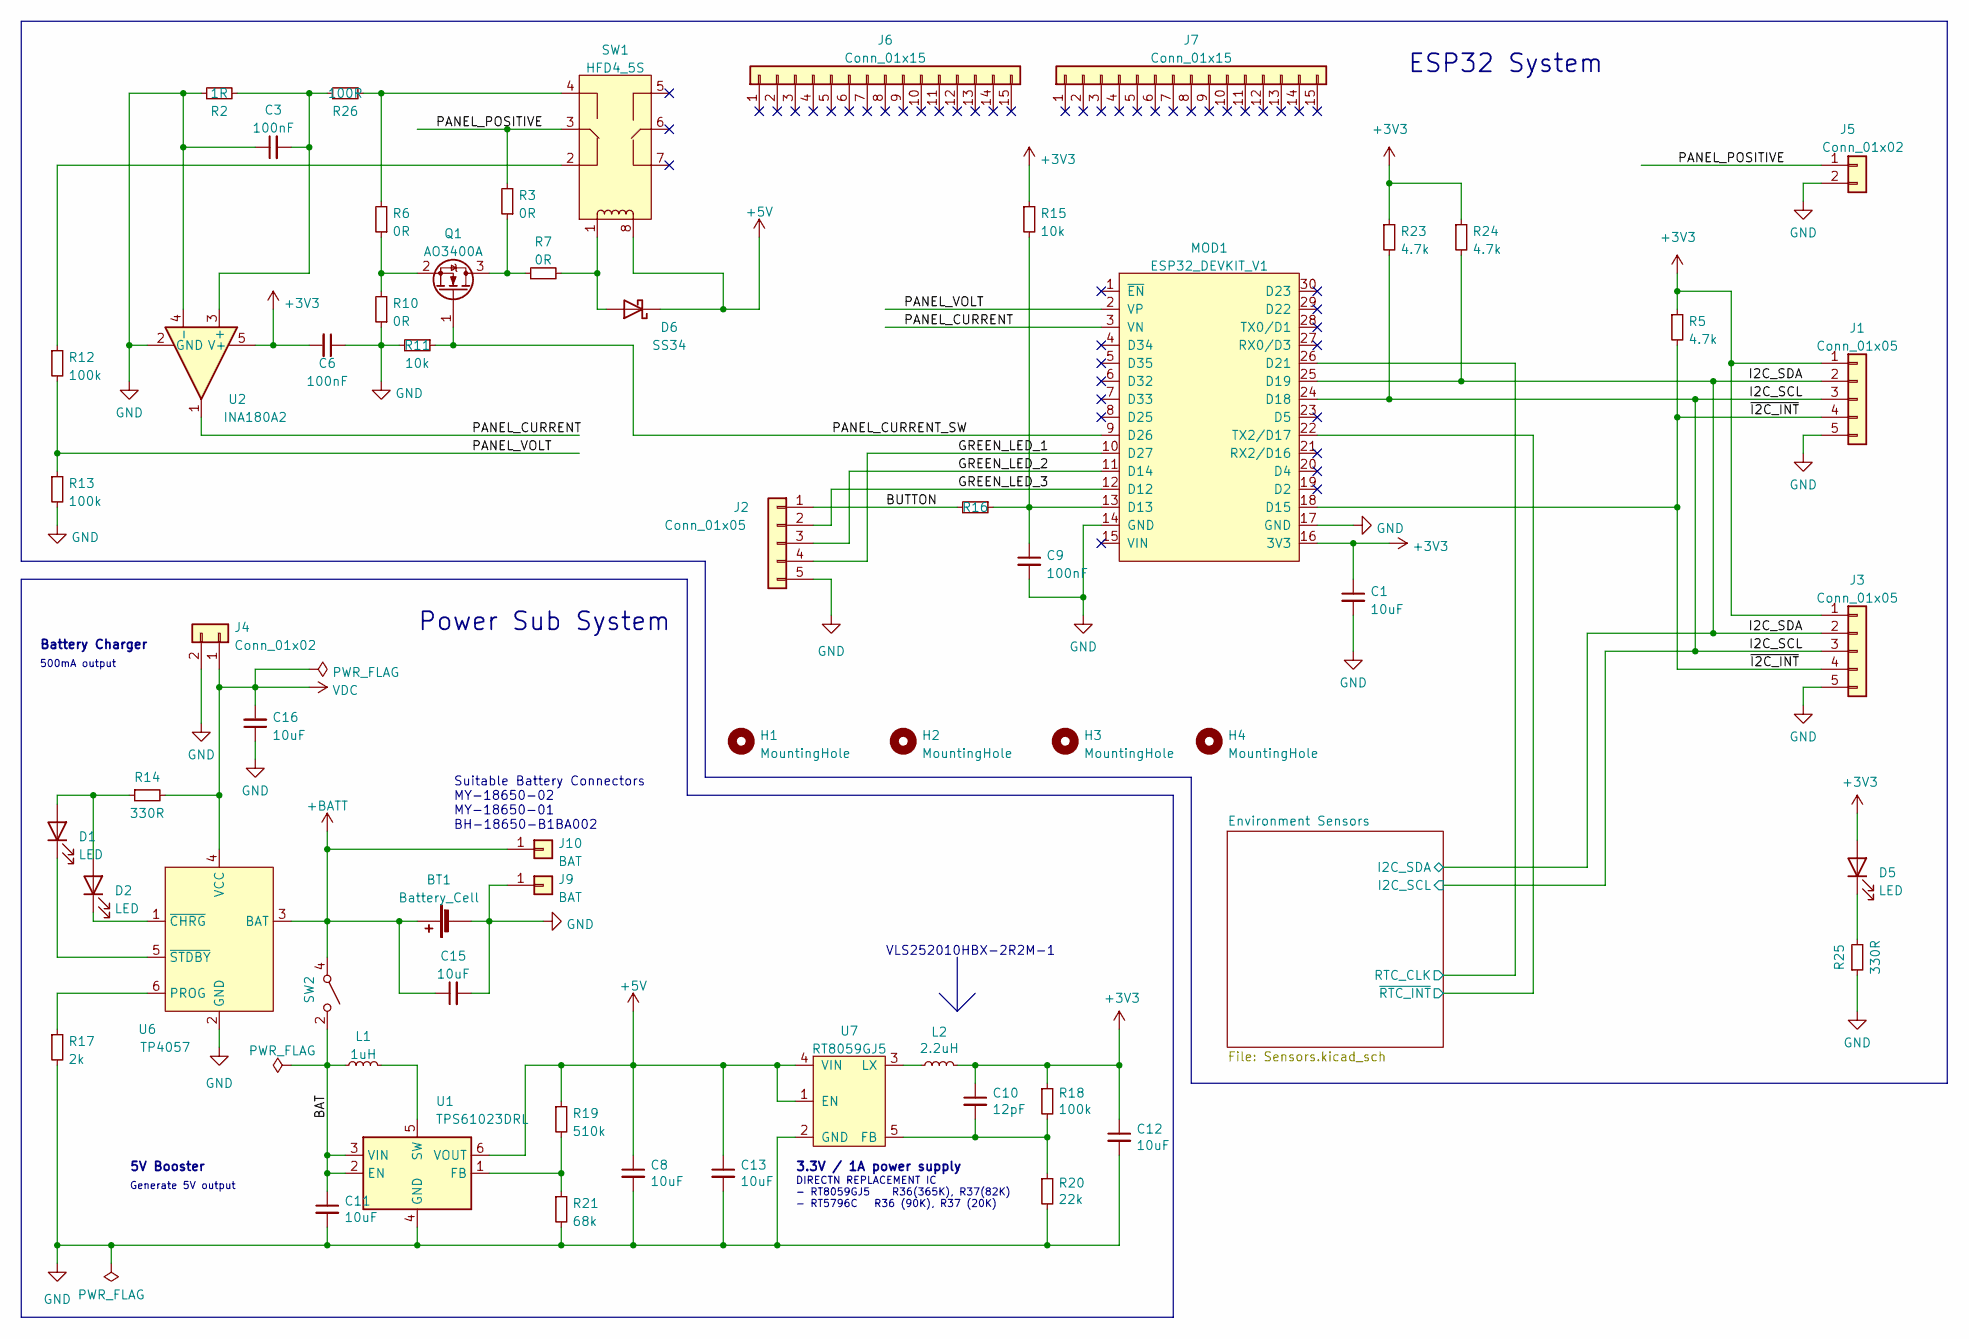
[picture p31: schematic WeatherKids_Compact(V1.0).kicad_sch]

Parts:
BT1: Battery_Cell; BatteryHolder_Keystone_1042_1x18650
C1: 10uF
C3, C6, C9: 100nF; C_0402_1005Metric
C8, C11, C12, C13, C15, C16: 10uF; C_0805_2012Metric
C10: 12pF; C_0402_1005Metric
D1, D2, D5: LED; LED_0805_2012Metric
D6: SS34; D_SMA
H1, H2, H3, H4: MountingHole; MountingHole_2.2mm_M2
J1, J2, J3: Conn_01x05; JST_PH_S5B-PH-K_1x05_P2.00mm_Horizontal
J4, J5: Conn_01x02; JST_PH_S2B-PH-K_1x02_P2.00mm_Horizontal
J6, J7: Conn_01x15; PinSocket_1x15_P2.54mm_Vertical
J9, J10: BAT; MY-18650-01
L1: 1uH; WPN252010U
L2: 2.2uH; WPN252010U
MOD1: ESP32_DEVKIT_V1; ESP32_DEVKIT_V1.0
Q1: AO3400A; SOT-23
R2: 1R; R_1206_3216Metric
R3, R6, R7, R10: 0R; R_0402_1005Metric
R5, R23, R24: 4.7k; R_0402_1005Metric
R11, R15: 10k; R_0402_1005Metric
R12, R13, R18: 100k; R_0402_1005Metric
R14, R25: 330R; R_0402_1005Metric
R16: 1k; R_0402_1005Metric
R17: 2k; R_0603_1608Metric
R19: 510k; R_0402_1005Metric
R20: 22k; R_0402_1005Metric
R21: 68k; R_0402_1005Metric
R26: 100R; R_1206_3216Metric
SW1: HFD4_5S; HDF4
SW2: SW_SPST; XKB5858-X-E
U1: TPS61023DRL; DRL0006A
U2: INA180A2; SOT-23-5
U6: TP4057; SOT-23-6
U7: RT8059GJ5; TSOT-23-5

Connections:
+3V3: C1.1, C6.2, C10.1, C12.1, D5.2 (A), J1.1, J3.1, L2.2, MOD1.16 (3V3), R5.1, R15.1, R18.1, R23.1, R24.1, U2.5 (V+); also elsewhere on the board
+5V: C8.1, C13.1, D6.1 (K), R19.1, SW1.8, U1.6 (VOUT), U7.1 (EN), U7.4 (VIN)
+BATT: BT1.1 (+), C15.1, J10.1, SW2.4 (A), U6.3 (BAT); also elsewhere on the board
/BAT: C11.1, L1.1, SW2.2 (B), U1.2 (EN), U1.3 (VIN)
/BUTTON: J2.1, R16.2
/Environment Sensors/RTC_CLK: MOD1.26 (D21); also elsewhere on the board
/Environment Sensors/~RTC_INT: MOD1.22 (TX2/D17); also elsewhere on the board
/GREEN_LED_1: J2.4, MOD1.10 (D27)
/GREEN_LED_2: J2.3, MOD1.11 (D14)
/GREEN_LED_3: J2.2, MOD1.12 (D12)
/I2C_SCL: J1.3, J3.3, MOD1.24 (D18), R23.2; also elsewhere on the board
/I2C_SDA: J1.2, J3.2, MOD1.25 (D19), R24.2; also elsewhere on the board
/PANEL_CURRENT: MOD1.3 (VN), U2.1
/PANEL_CURRENT_SW: MOD1.9 (D26), Q1.1 (G), R11.1
/PANEL_POSITIVE: J5.1, R3.2, SW1.3
/PANEL_VOLT: MOD1.2 (VP), R12.2, R13.1
/~I2C_INT: J1.4, J3.4, MOD1.18 (D15), R5.2
GND: BT1.2 (-), C1.2, C3.1, C6.1, C8.2, C9.2, C11.2, C12.2, C13.2, C15.2, C16.1, J1.5, J2.5, J3.5, J4.2, J5.2, J9.1, MOD1.14 (GND), MOD1.17 (GND), R2.1, R10.1, R11.2, R13.2, R17.2, R20.2, R21.2, R25.1, U1.4 (GND), U2.2 (GND), U2.4 (-), U6.2 (GND), U7.2 (GND); also elsewhere on the board
unnamed: C3.2, R2.2, R26.2, U2.3 (+)
unnamed: C9.1, MOD1.13 (D13), R15.2, R16.1
unnamed: C10.2, R18.2, R20.1, U7.5 (FB)
unnamed: D1.1 (K), U6.5 (~STDBY)
unnamed: D1.2 (A), D2.2 (A), R14.1
unnamed: D2.1 (K), U6.1 (~CHRG)
unnamed: D5.1 (K), R25.2
unnamed: D6.2 (A), R7.2, SW1.1
unnamed: L1.2, U1.5 (SW)
unnamed: L2.1, U7.3 (LX)
unnamed: Q1.2 (S), R6.1, R10.2
unnamed: Q1.3 (D), R3.1, R7.1
unnamed: R12.1, SW1.2
unnamed: R17.1, U6.6 (PROG)
unnamed: R19.2, R21.1, U1.1 (FB)
unnamed: R6.2, R26.1, SW1.4
VDC: C16.2, J4.1, R14.2, U6.4 (VCC)

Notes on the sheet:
Battery Charger
VLS252010HBX-2R2M-1
Power Sub System
Suitable Battery Connectors MY-18650-02 MY-18650-01 BH-18650-B1BA002
500mA output
DIRECTN REPLACEMENT IC - RT8059GJ5 R36(365K), R37(82K) - RT5796C R36 (90K), R37 (20K)
ESP32 System
5V Booster
Generate 5V output
3.3V / 1A power supply

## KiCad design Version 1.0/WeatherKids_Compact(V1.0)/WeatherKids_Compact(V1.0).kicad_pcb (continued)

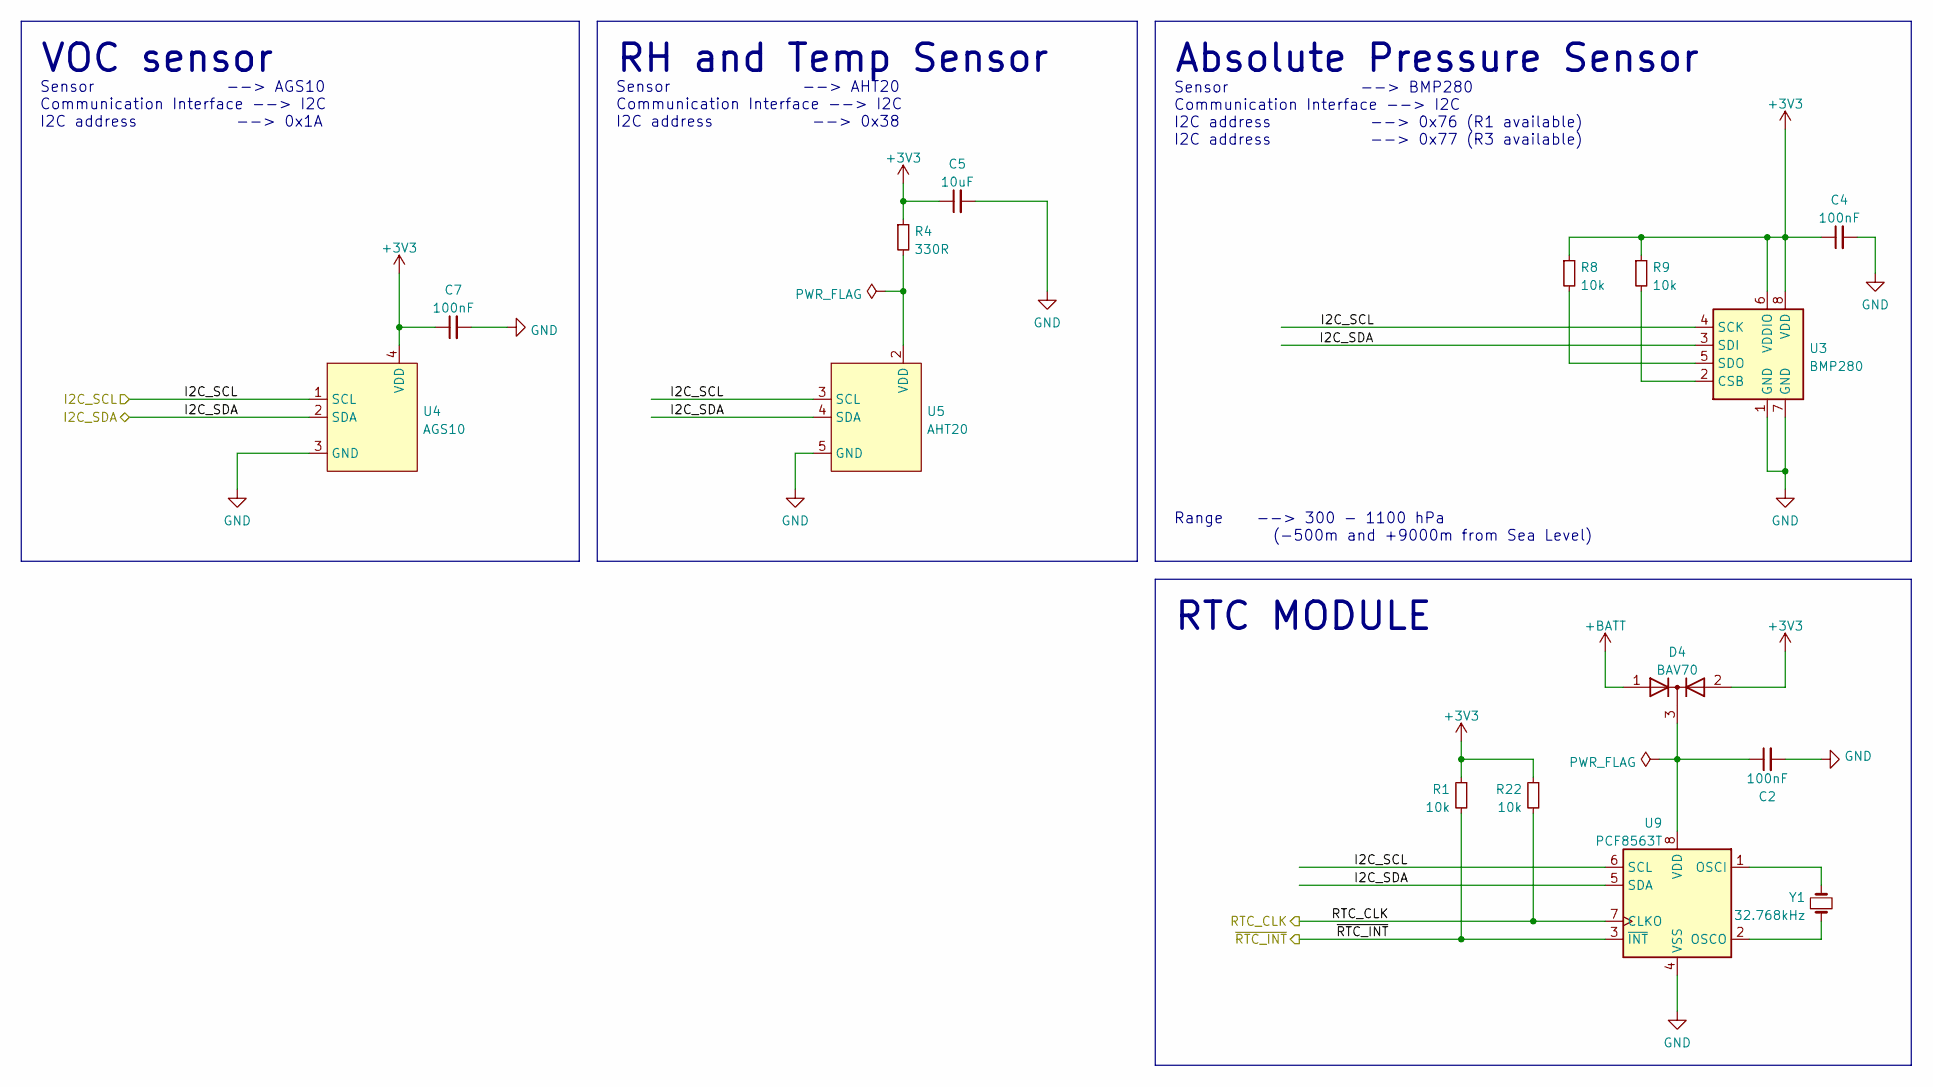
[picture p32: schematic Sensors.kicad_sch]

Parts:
C2, C4, C7: 100nF; C_0402_1005Metric
C5: 10uF; C_0805_2012Metric
D4: BAV70; SOT-23
R1, R8, R9, R22: 10k; R_0402_1005Metric
R4: 330R; R_0402_1005Metric
U3: BMP280; Bosch_LGA-8_2x2.5mm_P0.65mm_ClockwisePinNumbering
U4: AGS10
U5: AHT20
U9: PCF8563T; SOIC-8_3.9x4.9mm_P1.27mm
Y1: 32.768kHz; Crystal_SMD_3215-2Pin_3.2x1.5mm

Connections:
+3V3: C4.1, C5.1, C7.1, D4.2 (A), R1.1, R4.1, R8.1, R9.1, R22.1, U3.6 (VDDIO), U3.8 (VDD), U4.4 (VDD); also elsewhere on the board
+BATT: D4.1 (A); also elsewhere on the board
/Environment Sensors/RTC_CLK: R22.2, U9.7 (CLKO); also elsewhere on the board
/Environment Sensors/~RTC_INT: R1.2, U9.3 (~INT); also elsewhere on the board
/I2C_SCL: U3.4 (SCK), U4.1 (SCL), U5.3 (SCL), U9.6 (SCL); also elsewhere on the board
/I2C_SDA: U3.3 (SDI), U4.2 (SDA), U5.4 (SDA), U9.5 (SDA); also elsewhere on the board
GND: C2.2, C4.2, C5.2, C7.2, U3.1 (GND), U3.7 (GND), U4.3 (GND), U5.5 (GND), U9.4 (VSS); also elsewhere on the board
unnamed: C2.1, D4.3 (K), U9.8 (VDD)
unnamed: R4.2, U5.2 (VDD)
unnamed: R8.2, U3.5 (SDO)
unnamed: R9.2, U3.2 (CSB)
unnamed: U9.1 (OSCI), Y1.2
unnamed: U9.2 (OSCO), Y1.1

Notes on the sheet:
Sensor --> AGS10 Communication Interface --> I2C I2C address --> 0x1A
Sensor --> BMP280 Communication Interface --> I2C I2C address --> 0x76 (R1 available) I2C address --> 0x77 (R3 available)
Range --> 300 - 1100 hPa (-500m and +9000m from Sea Level)
RH and Temp Sensor
RTC MODULE
Sensor --> AHT20 Communication Interface --> I2C I2C address --> 0x38
VOC sensor
Absolute Pressure Sensor

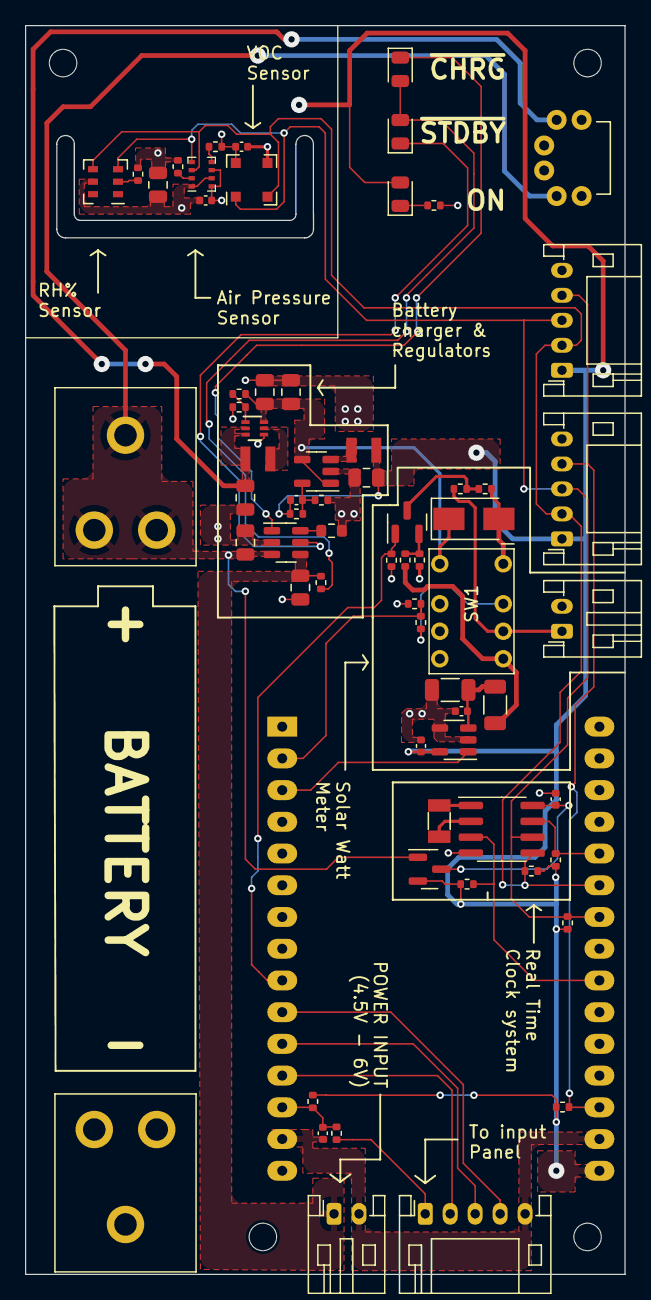
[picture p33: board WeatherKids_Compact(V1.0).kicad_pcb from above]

Board: 2 copper layers, 48.0 x 100.0 mm, 71 parts (0 on the bottom side), 41 nets.

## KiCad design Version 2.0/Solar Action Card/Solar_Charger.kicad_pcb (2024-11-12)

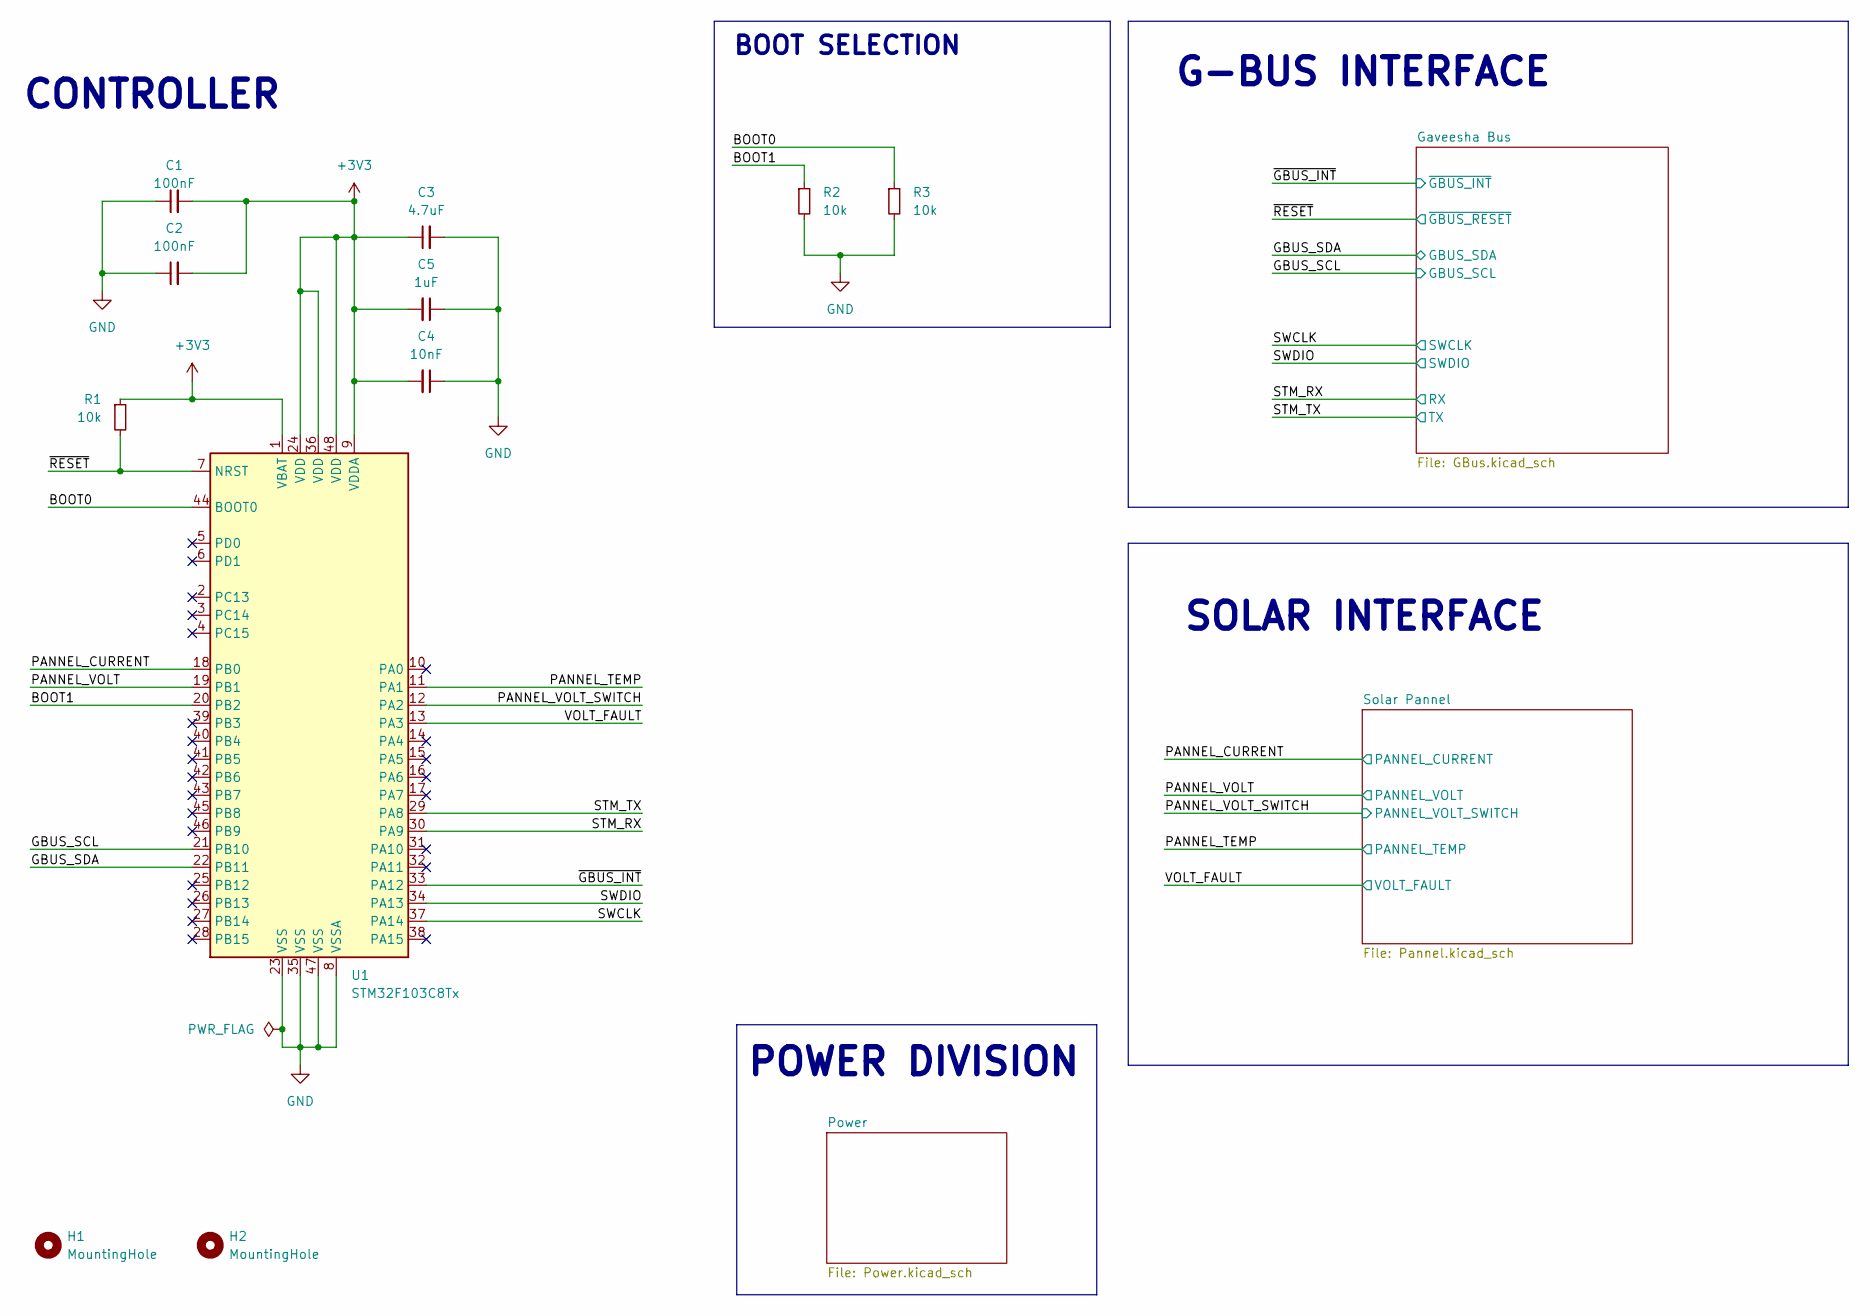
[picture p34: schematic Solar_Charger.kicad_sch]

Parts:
C1, C2: 100nF; C_0603_1608Metric; JLC PCB Part No. C1525
C3: 4.7uF; C_0402_1005Metric; JLC PCB Part No C23733
C4: 10nF; C_0402_1005Metric; JLC PCB Part No. C15195
C5: 1uF; C_0402_1005Metric; JLC PCB Part No. C52923
H1, H2: MountingHole; MountingHole_2.2mm_M2
R1, R2, R3: 10k; R_0402_1005Metric
U1: STM32F103C8Tx; LQFP-48_7x7mm_P0.5mm

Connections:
+3V3: C1.2, C2.2, C3.1, C4.2, C5.2, R1.1, U1.1 (VBAT), U1.9 (VDDA), U1.24 (VDD), U1.36 (VDD), U1.48 (VDD); also elsewhere on the board
/BOOT0: R3.1, U1.44 (BOOT0)
/BOOT1: R2.1, U1.20 (PB2)
/GBUS_SCL: U1.21 (PB10); also elsewhere on the board
/GBUS_SDA: U1.22 (PB11); also elsewhere on the board
/PANNEL_CURRENT: U1.18 (PB0); also elsewhere on the board
/PANNEL_TEMP: U1.11 (PA1); also elsewhere on the board
/PANNEL_VOLT: U1.19 (PB1); also elsewhere on the board
/PANNEL_VOLT_SWITCH: U1.12 (PA2); also elsewhere on the board
/STM_RX: U1.30 (PA9); also elsewhere on the board
/STM_TX: U1.29 (PA8); also elsewhere on the board
/SWCLK: U1.37 (PA14); also elsewhere on the board
/SWDIO: U1.34 (PA13); also elsewhere on the board
/VOLT_FAULT: U1.13 (PA3); also elsewhere on the board
/~GBUS_INT: U1.33 (PA12); also elsewhere on the board
/~RESET: R1.2, U1.7 (NRST); also elsewhere on the board
GND: C1.1, C2.1, C3.2, C4.1, C5.1, R2.2, R3.2, U1.8 (VSSA), U1.23 (VSS), U1.35 (VSS), U1.47 (VSS); also elsewhere on the board

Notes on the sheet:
CONTROLLER
BOOT SELECTION
POWER DIVISION
SOLAR INTERFACE
G-BUS INTERFACE

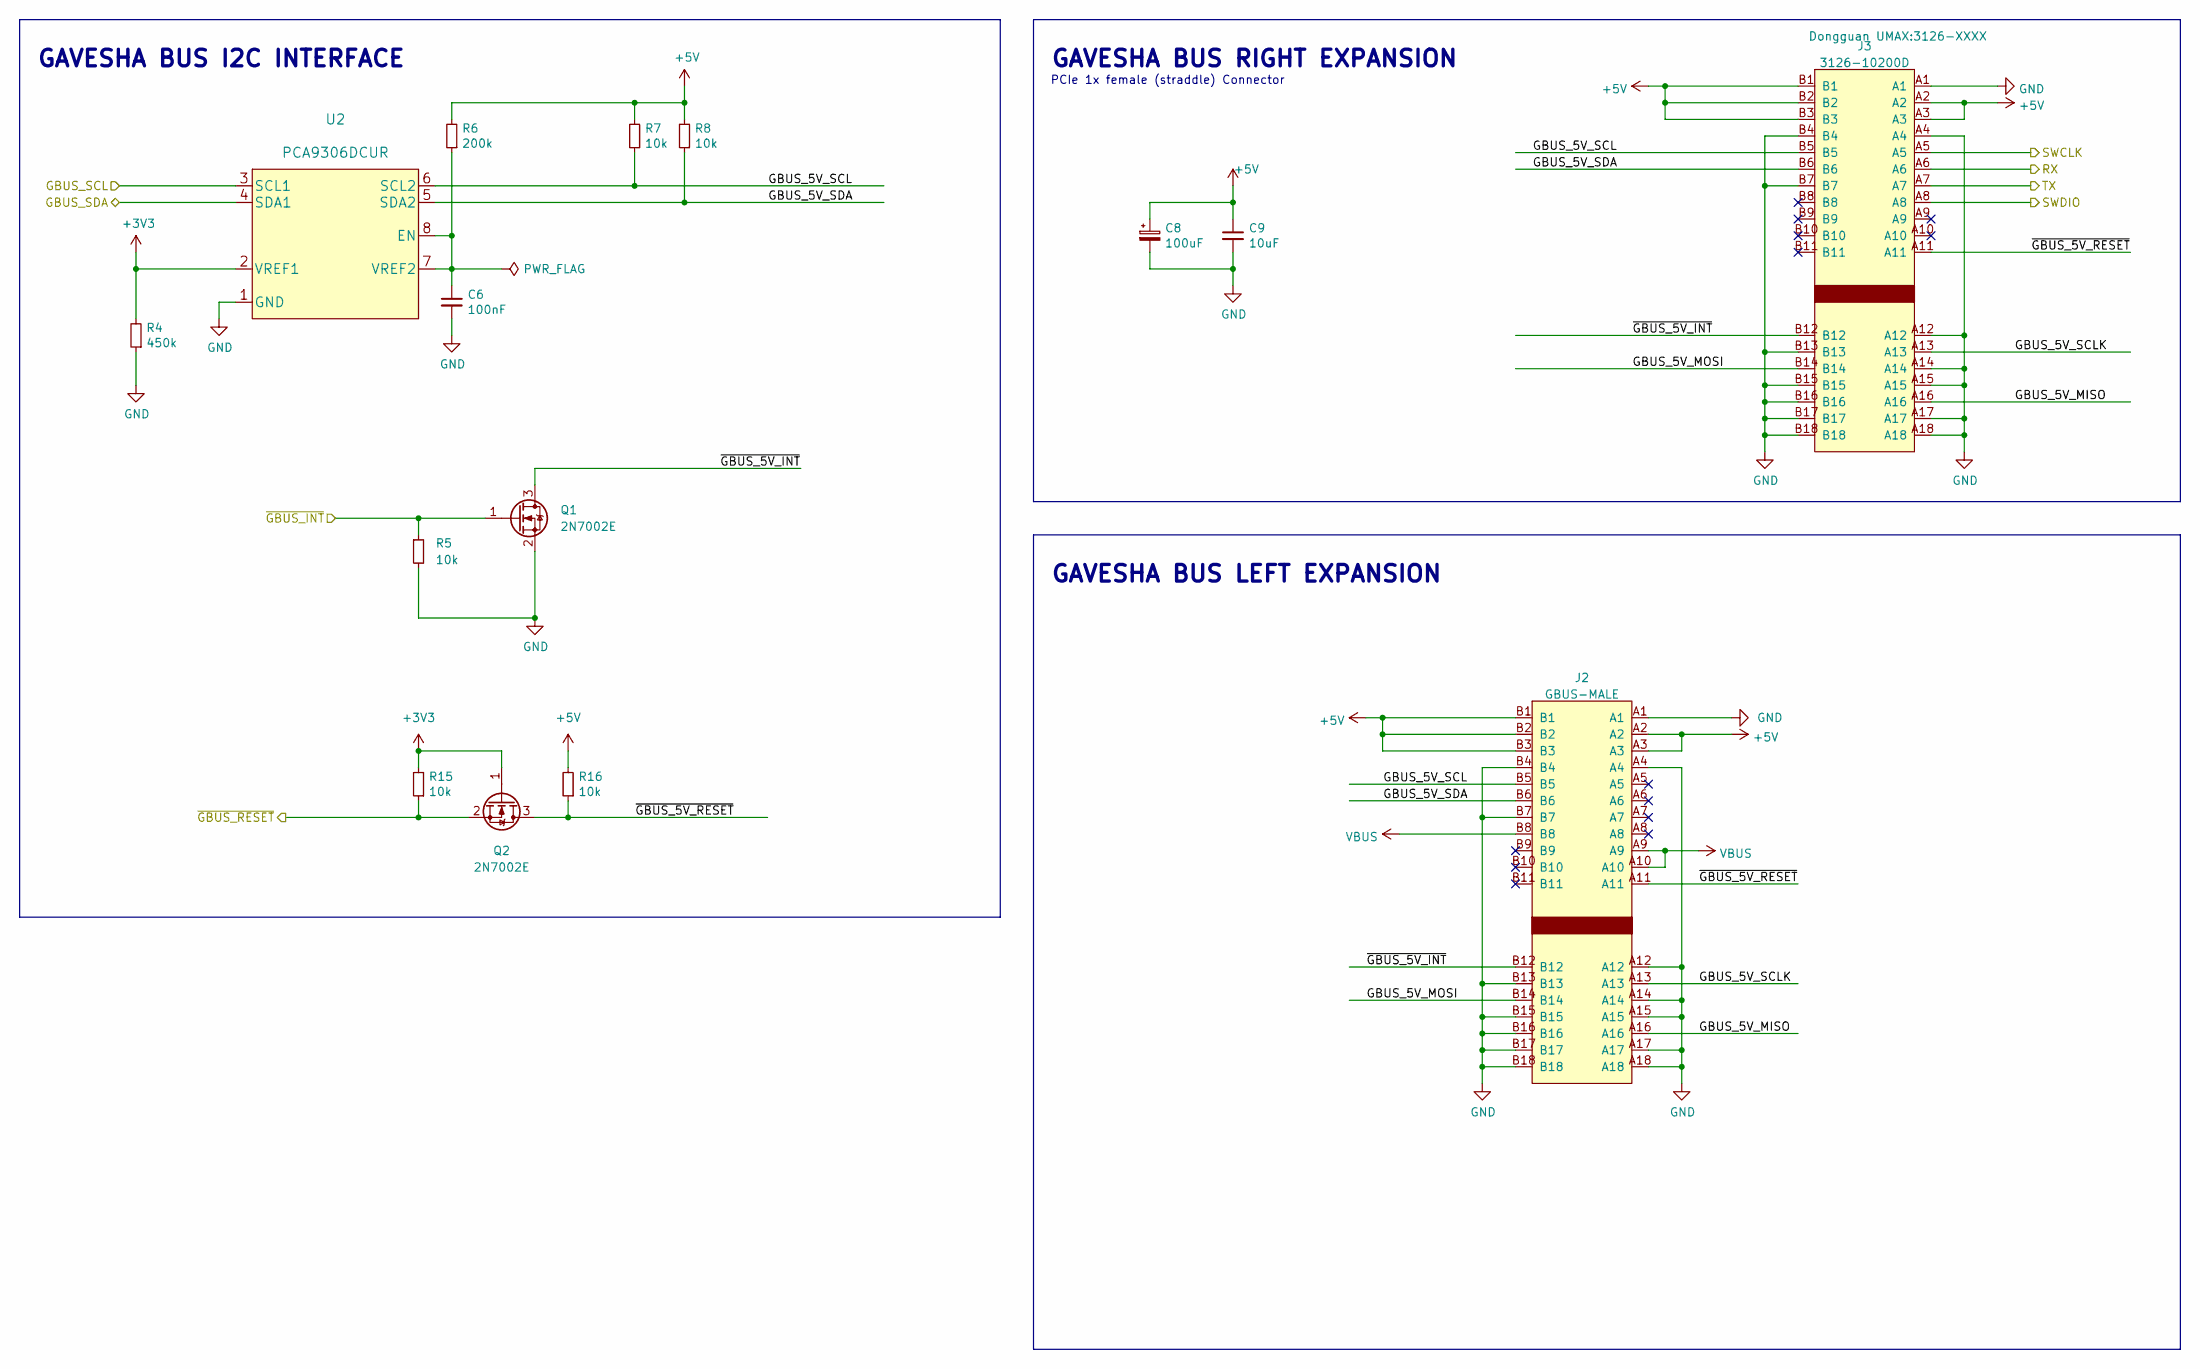
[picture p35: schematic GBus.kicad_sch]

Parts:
C6: 100nF; C_0402_1005Metric
C8: 100uF; CP_EIA-3528-12_Kemet-T
C9: 10uF; C_0805_2012Metric
J2: GBUS-MALE; GBUS_MALE
J3: 3126-10200D; 3126-XXXX
Q1, Q2: 2N7002E; SOT-23
R4: 450k; R_0402_1005Metric
R5, R7, R8, R15, R16: 10k; R_0402_1005Metric
R6: 200k; R_0402_1005Metric
U2: PCA9306DCUR

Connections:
+3V3: Q2.1 (G), R4.2, R15.2, U2.2 (VREF1); also elsewhere on the board
+5V: C8.1, C9.1, J2.A2, J2.A3, J2.B1, J2.B2, J2.B3, J3.A2, J3.A3, J3.B1, J3.B2, J3.B3, R6.2, R7.2, R8.2, R16.2; also elsewhere on the board
/GBUS_SCL: U2.3 (SCL1); also elsewhere on the board
/GBUS_SDA: U2.4 (SDA1); also elsewhere on the board
/Gaveesha Bus/GBUS_5V_MISO: J2.A16, J3.A16
/Gaveesha Bus/GBUS_5V_MOSI: J2.B14, J3.B14
/Gaveesha Bus/GBUS_5V_SCL: J2.B5, J3.B5, R7.1, U2.6 (SCL2)
/Gaveesha Bus/GBUS_5V_SCLK: J2.A13, J3.A13
/Gaveesha Bus/GBUS_5V_SDA: J2.B6, J3.B6, R8.1, U2.5 (SDA2)
/Gaveesha Bus/~GBUS_5V_INT: J2.B12, J3.B12, Q1.3 (D)
/Gaveesha Bus/~GBUS_5V_RESET: J2.A11, J3.A11, Q2.3 (D), R16.1
/STM_RX: J3.A6; also elsewhere on the board
/STM_TX: J3.A7; also elsewhere on the board
/SWCLK: J3.A5; also elsewhere on the board
/SWDIO: J3.A8; also elsewhere on the board
/~GBUS_INT: Q1.1 (G), R5.1; also elsewhere on the board
/~RESET: Q2.2 (S), R15.1; also elsewhere on the board
GND: C6.2, C8.2, C9.2, J2.A1, J2.A4, J2.A12, J2.A14, J2.A15, J2.A17, J2.A18, J2.B4, J2.B7, J2.B13, J2.B15, J2.B16, J2.B17, J2.B18, J3.A1, J3.A4, J3.A12, J3.A14, J3.A15, J3.A17, J3.A18, J3.B4, J3.B7, J3.B13, J3.B15, J3.B16, J3.B17, J3.B18, Q1.2 (S), R4.1, R5.2, U2.1 (GND); also elsewhere on the board
unnamed: C6.1, R6.1, U2.7 (VREF2), U2.8 (EN)
VBUS: J2.A9, J2.A10, J2.B8; also elsewhere on the board

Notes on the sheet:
PCIe 1x female (straddle) Connector
GAVESHA BUS LEFT EXPANSION
GAVESHA BUS I2C INTERFACE
GAVESHA BUS RIGHT EXPANSION


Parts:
C16: 100nF; R_0603_1608Metric
J4: USB_C_Receptacle_USB2.0; USB_C_Receptacle_HRO_TYPE-C-31-M-12
R10: 750k; R_0603_1608Metric
R11: 270k; R_0603_1608Metric
R12: 10k; R_0603_1608Metric
R13: 50m; R_1206_3216Metric; LCSC Part# C912768
R14: 130R; R_Axial_DIN0516_L15.5mm_D5.0mm_P20.32mm_Horizontal; LCSC part# C119572
U9: TPS1H000AQDGNRQ1; MSOP-8-1EP_3x3mm_P0.65mm_EP1.95x2.15mm
U10: INA180A1; SOT-23-5

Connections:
+3V3: R12.1, U10.5 (V+); also elsewhere on the board
/PANNEL_CURRENT: U10.1; also elsewhere on the board
/PANNEL_TEMP: J4.A5 (CC1), J4.B5 (CC2), R12.2; also elsewhere on the board
/PANNEL_VOLT: R10.2, R11.1; also elsewhere on the board
/PANNEL_VOLT_SWITCH: U9.1 (IN); also elsewhere on the board
/Solar Pannel/PANNEL_POSITIVE: J4.A4 (VBUS), J4.A9 (VBUS), J4.B4 (VBUS), J4.B9 (VBUS), R13.1, U10.3 (+)
/VOLT_FAULT: U9.3 (FAULT#); also elsewhere on the board
GND: C16.2, J4.A1 (GND), J4.A12 (GND), J4.B1 (GND), J4.B12 (GND), J4.S1 (SHIELD), R11.2, R14.2, U9.2 (DAIG_EN), U9.4 (CL), U9.6 (GND), U9.9 (EP), U10.2 (GND); also elsewhere on the board
unnamed: C16.1, U9.5 (DELAY)
unnamed: R14.1, U9.7 (OUT)
VDC: R10.1, R13.2, U9.8 (VS), U10.4 (-); also elsewhere on the board

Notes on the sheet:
Value of R depend on Temp
CURRENT SENSOR
VOLT SENSOR
USB C PORT
R value Seeting for different INA180 Gain settings assuming DAC operates at 1.024V ref INA180A1 (G=20) INA180A2 (G=50) INA180A3 (G=100) INA180A4 (G=200)


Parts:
C10: 0.1uF; C_0603_1608Metric
C11: 0.1uF; C_0805_2012Metric
C12: 10uF; C_0402_1005Metric
C13: 100nF; C_0402_1005Metric
C14: 3.3nF; C_0402_1005Metric
C15: 22uF; C_0603_1608Metric
L1: 2.2uH; L_Sunlord_MWSA0518_5.4x5.2mm; LCSC C408345
R9: 100k; R_0402_1005Metric
U7: AZ1117-3.3; SOT-223
U8: TPS62133; VQFN-16-1EP_3x3mm_P0.5mm_EP1.68x1.68mm_ThermalVias; LCSC C2653764

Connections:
+3V3: C11.1, U7.2 (VO); also elsewhere on the board
+5V: C10.1, U7.3 (VI); also elsewhere on the board
GND: C10.2, C11.2, C12.1, C13.1, C14.2, C15.2, U7.1 (GND), U8.5 (FB), U8.6 (AGND), U8.7 (FSW), U8.8 (DEF), U8.15 (PGND), U8.16 (PGND), U8.17 (EP); also elsewhere on the board
unnamed: C14.1, U8.9 (SS/TR)
unnamed: L1.1, U8.1 (SW), U8.2 (SW), U8.3 (SW)
unnamed: R9.1, U8.4 (PG)
VBUS: C15.1, L1.2, R9.2, U8.14 (VOS); also elsewhere on the board
VDC: C12.2, C13.2, U8.10 (AVIN), U8.11 (PVIN), U8.12 (PVIN), U8.13 (EN); also elsewhere on the board

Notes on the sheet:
POWER SUB SYSTEM
5v BUCK CONVERTER - 3A
3.3V / 1A power supply


Board: 2 copper layers, 41.4 x 53.0 mm, 45 parts (0 on the bottom side), 34 nets.

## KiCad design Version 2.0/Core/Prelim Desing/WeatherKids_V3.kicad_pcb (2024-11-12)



Board: 2 copper layers, 53.0 x 70.0 mm, 69 parts (2 on the bottom side), 43 nets.

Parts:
C2, C4, C5, C6, C9, C12, C14, C21: 10uF; C_0805_2012Metric
C7: 0.1uF; C_0402_1005Metric
C8: 22uF; C_0603_1608Metric
C10: 1nF; C_0402_1005Metric
C11: 12pF; C_0402_1005Metric
C13, C15, C16, C17, C18: 100nF; C_0402_1005Metric
C19, C20: 100uF; CP_EIA-3528-12_Kemet-T
D1, D2, D6: LED; LED_0805_2012Metric
D3, D4, D5: SS54; D_SMA
D7: BAV70; SOT-23
H1, H2: MountingHole; MountingHole_2.2mm_M2
J4: Conn_01x02; JST_PH_S2B-PH-K_1x02_P2.00mm_Horizontal
J5, J8: BAT; SolderWire-2.5sqmm_1x01_D2.4mm_OD4.4mm
J10: 3126-10200D; 3126-XXXX
L1: 1uH; WPN252010U
L2: 2.2uH; WPN252010U
R1: 2k; R_0603_1608Metric
R2, R6, R12: 330R; R_0402_1005Metric
R3: 510k; R_0402_1005Metric
R4: 68k; R_0402_1005Metric
R5, R13, R14, R15, R17, R19, R20, R21, R22: 10k; R_0402_1005Metric
R7: 100k; R_0402_1005Metric
R8: 22k; R_0402_1005Metric
R16: 450k; R_0402_1005Metric
R18: 200k; R_0402_1005Metric
SW1: SW_SPST; XKB5858-X-E
U1: TP4057; SOT-23-6
U2: TPS61023DRL; DRL0006A
U3: ESP32-WROOM-32D; ESP32-WROOM-32
U4: RT8059GJ5; TSOT-23-5
U5: AGS10
U6: AHT20
U7: PCF8563T; SOIC-8_3.9x4.9mm_P1.27mm
U8: BMP280; Bosch_LGA-8_2x2.5mm_P0.65mm_ClockwisePinNumbering
U9: PCA9306DCUR
U10, U11, U12, U13, U14: SN74LV1T34DVBR; SOT-23-5
Y1: 32.768kHz; Crystal_SMD_3215-2Pin_3.2x1.5mm

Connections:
+3V3: C7.2, C8.2, C11.1, C12.1, C13.1, C14.1, C16.1, D6.2 (A), D7.2 (A), L2.2, R5.1, R7.1, R12.1, R13.1, R14.1, R15.1, R16.2, R17.2, R20.2, U3.2 (VDD), U5.4 (VDD), U8.6 (VDDIO), U8.8 (VDD), U9.2 (VREF1), U12.5 (VCC), U13.5 (VCC)
+5V: C9.1, C19.1, C20.1, C21.1, D4.1 (K), D5.1 (K), J10.A2, J10.A3, J10.B1, J10.B2, J10.B3, R18.2, R19.2, R21.2, R22.2, U4.1 (EN), U4.4 (VIN), U10.5 (VCC), U11.5 (VCC), U14.5 (VCC)
+BATT: C5.1, D7.1 (A), J5.1, SW1.4 (A), U1.3 (BAT)
/BAT: C4.1, D3.1 (K), L1.1, U2.2 (EN), U2.3 (VIN)
/Bus/GBUS_5V_MISO: J10.A16, U12.2 (A)
/Bus/GBUS_5V_MOSI: J10.B14, U11.4 (Y)
/Bus/GBUS_5V_SCL: J10.B5, R19.1, U9.6 (SCL2)
/Bus/GBUS_5V_SCLK: J10.A13, U10.4 (Y)
/Bus/GBUS_5V_SDA: J10.B6, R21.1, U9.5 (SDA2)
/Bus/~GBUS_5V_INT: J10.B12, R22.1, U13.2 (A)
/Bus/~GBUS_5V_RESET: J10.A11, U14.4 (Y)
/GBUS.CLK: U3.30 (IO18), U10.2 (A)
/GBUS.DETECT: C18.1, J10.B17, R20.1, U3.7 (IO35)
/GBUS.MISO: U3.31 (IO19), U12.4 (Y)
/GBUS.MOSI: U3.37 (IO23), U11.2 (A)
/GBUS.SCL: U3.33 (IO21), U9.3 (SCL1)
/GBUS.SDA: U3.36 (IO22), U9.4 (SDA1)
/GBUS.~INT: U3.6 (IO34), U13.4 (Y)
/GBUS.~RESET: R17.1, U3.29 (IO5), U14.2 (A)
/I2C_SCL: U3.10 (IO25), U5.1 (SCL), U6.3 (SCL), U7.6 (SCL), U8.4 (SCK)
/I2C_SDA: U3.11 (IO26), U5.2 (SDA), U6.4 (SDA), U7.5 (SDA), U8.3 (SDI)
/~ESP23_EN: C10.1, R5.2, U3.3 (EN)
/~RTC_INT: R13.2, U3.27 (IO16), U7.3 (~INT)
GND: C2.1, C4.2, C5.2, C6.2, C7.1, C8.1, C9.2, C10.2, C12.2, C13.2, C14.2, C15.2, C16.2, C17.2, C18.2, C19.2, C20.2, C21.2, J4.2, J8.1, J10.A1, J10.A4, J10.A12, J10.A14, J10.A15, J10.A17, J10.A18, J10.B4, J10.B7, J10.B13, J10.B15, J10.B16, J10.B18, R1.2, R4.2, R6.1, R8.2, R16.1, U1.2 (GND), U2.4 (GND), U3.1 (GND), U3.15 (GND), U3.38 (GND), U3.39 (GND), U4.2 (GND), U5.3 (GND), U6.5 (GND), U7.4 (VSS), U8.1 (GND), U8.7 (GND), U9.1 (GND), U10.3 (GND), U11.3 (GND), U12.3 (GND), U13.3 (GND), U14.3 (GND)
unnamed: C6.1, D4.2 (A), R3.1, U2.6 (VOUT)
unnamed: C11.2, R7.2, R8.1, U4.5 (FB)
unnamed: C15.1, D7.3 (K), U7.8 (VDD)
unnamed: C17.1, R18.1, U9.7 (VREF2), U9.8 (EN)
unnamed: D1.1 (K), U1.5 (~STDBY)
unnamed: D1.2 (A), D2.2 (A), R2.1
unnamed: D2.1 (K), U1.1 (~CHRG)
unnamed: D3.2 (A), SW1.2 (B)
unnamed: D6.1 (K), R6.2
unnamed: L1.2, U2.5 (SW)
unnamed: L2.1, U4.3 (LX)
unnamed: R1.1, U1.6 (PROG)
unnamed: R3.2, R4.1, U2.1 (FB)
unnamed: R12.2, U6.2 (VDD)
unnamed: R14.2, U8.5 (SDO)
unnamed: R15.2, U8.2 (CSB)
unnamed: U7.1 (OSCI), Y1.2
unnamed: U7.2 (OSCO), Y1.1
VBUS: C2.2, D5.2 (A), J4.1, R2.2, U1.4 (VCC)

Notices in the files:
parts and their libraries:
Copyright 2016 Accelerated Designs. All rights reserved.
